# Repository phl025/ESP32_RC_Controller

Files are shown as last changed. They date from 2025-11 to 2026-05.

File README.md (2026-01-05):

# Arduino RC Controller for ESP32



## Description
This is a RC controller including engine sound player, PWM outputs for servos, ESC drivers and digital outputs.

## Details
It is based on *'Rc_Engine_Sound_ESP32'* : https://github.com/TheDIYGuy999/Rc_Engine_Sound_ESP32.

If you need to use it for trucks, cars, or other vehicles, it is easier to use the original version.

This version is modified for my boats.

## Software
Many functions are converted to 'object-oriented programming', such as :
- Receiver : RxBase, RxPpm, RxCrsf, RxSbus, RxPwm
- RX Channels : RxChannel, chTrigger
- ESC : escDriver for RZ7886 or IBT2
- ...

## Hardware
You can use the original hardware, but a modified version is available. 

Modifications : 
- Add pins for diagnostics or futures extensions.
- CH5, CH6 rename to IN1, IN2 (could be use for PWM input CH5, CH6 or 'motor encoder')
- Add input IN3, pin 39
- Add CH7, pin 15 (for steering servo in case of 3x ECS)

## PCB

See "hardware/pictures/"

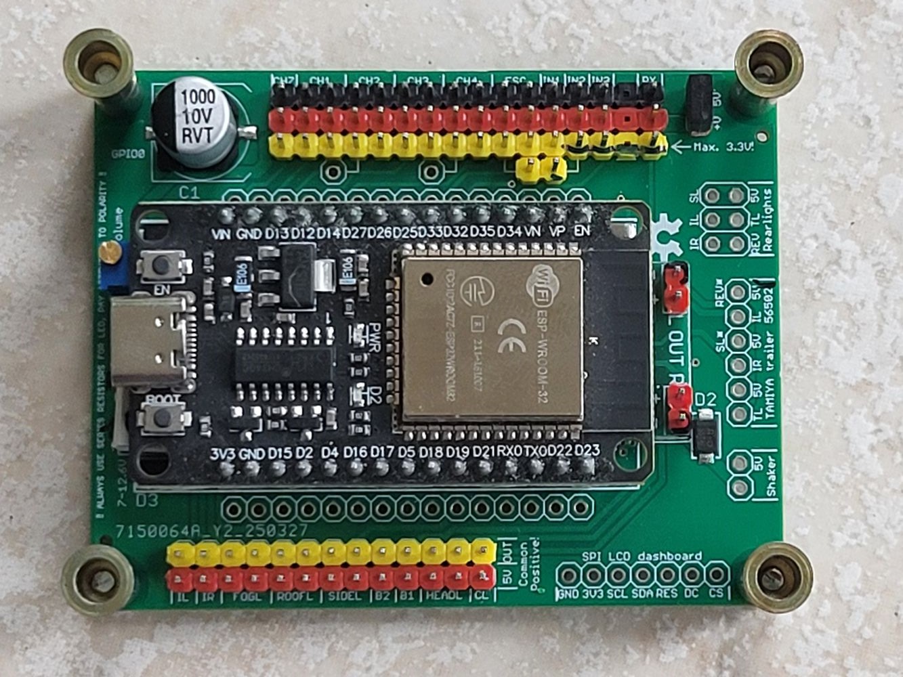
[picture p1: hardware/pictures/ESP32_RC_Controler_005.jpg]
This is a sample image.


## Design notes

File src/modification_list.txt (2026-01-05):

*
* Liste des Modifications
*

*
* Tests RX Communication modes (2025-11-09)
* 
CRSF Communication : TX16S + RP3-H (CRSF) : OK, 16ch
SBUS_Communication : TX16S + RP3-H (SBUS) : OK,
PWM_Communication  : TX16S + ER6 (PWM pins 13, 12, 14, 27, 35, 34) : OK, 4 and 6ch 
PPM_Communication  : MC2010 (Trainer output) : OK, but stability not correct (error with integrator .rxd) (2025-11-24)
--> Test https://github.com/dimag0g/PPM-reader/tree/master

*
* Models definition
*
2025-09-26 :
  - Add 0_Model.h -> Models list, call "models/model.h"
  - Add \Models and models .h
    Each 'model.h' include 
    - sound definition (idem DIYGuy999 template)
    - Remote configuration (like but does not match the DIYGuy999 template)
  Benefit : Only one file by model
  
*
* MAJ noms / convention
*
2025-09-18
  - MAJ des noms de Class, fonctions, variables.. pour coller a la convention de nomage jointe.
  - Ajout de \documents, \hardware

*
* Test PWM communication (inputs, using RTM)
*
2025-10-02
  - Ajout rxPwm.h et rxPwm.cpp
  - Test PWM_Communication (version 4 canaux)

*
* Test SBUS / CRSF
*
2025-09-26
  - Test CRSF après mise a jour de TX16S, ER6, RP3-H en version 3.6.0 -> OK sur les 16 canaux

2025-09-10 
  - Ajout, test 'rxSbus'
    -> 16 canaux OK
    -> failSafe par timeout 100ms OK
  - rxBase
    - processFailSafe() : Ajout MAJ channel[].rxd

2025-09-08
  - Premiers test, résultat moyen
  -> 16 canaux OK
  -> pas de détection failSafe, pb de temps ~200us pour 100Hz / 10000us (????)

*
* Corrections diverses pour CRSF jusqu'à 16 chanaux (15 et 16 NOK)
*
2025-09-07
  - Modifs diveres, erreurs avec 'nb_channels' et 'nb_channels + 1'
  - Limitations de nb_channels fonction de RX_CHANNELS et MAX_CHANNELS

*
* Ajout de RxChannel
*
2025-08-28 :
  - Ajout de RxChannel (objet)
  - RxChannel[] est intégré dans rxBase, 
  - raw_channel[], rx_channel[], rxd_channel[] : sont supprimés
  - Tests semblent OK 

*
* Test module sonore :
*
2025-08-13 :
  - Idle engine 	: OK,
	- Rev Engine 	: OK,
  - Horn (sound1) : OK (08-2x)
  - Winch (sound2) : OK (08-2x)

*
* Test ESC
*
2025-04-23 : 
- ESC1 a ESC3 OK, avec allocation dynamique
- CRSFForArduino, testé : OK, A revoir pour faire un objet

2025-04-22 : 
- ESC1 et ESC2 OK, avec allocation statique "escDriver esc_1(1, MCPWM_UNIT_1, ..);"
  -> Les variables de la classe doivent être déclarées dans escDriver.h 
     (Ne fonctionne pas dans .cpp, erreur d'allocation mémoire)

2025-04-19 :
- Test ESC_1 : OK
  Ajout gestion des rampes, idem variateur AVR-
- Test ESC_2 : 
	--> NOK, reboot CPU  

2025-04-15 :
- Test rxCrsf avec TX16S + ER6 : OK
  Les canaux 1 a 9 sont mis a jour

2025-04-14 :
- Test rxPpm avec MC2020 : OK (pour controle)

*
* Tests modules externes
*
CRSFForArduino : 
- Semble pas stable, saut de valeurs alors que c'est OK avec "AlfredoCRSF".
- Retiré du projet (2025-05-14)

*
* EOF
*

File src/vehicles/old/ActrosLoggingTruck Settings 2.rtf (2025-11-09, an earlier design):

/* ******* RECOMMENDED Audacity Settings: 22'050 Hz, 8 bit PCM **********

// Sound files converted with: https://bitluni.net/wp-content/uploads/2018/01/Audio2Header.html
// converter code by bitluni (send him a high five, if you like the code)

Recommended parts & settings for TAMIYA King Hauler:

ESC: HOBBYWING QUICRUN WP Crawler Brushed with the following settings:
1: 3
2: 1
3: 3
4: 3
5: 4
6: 2
7: 9
8: 1
9: 8 (change it, important)
10: 4
11: 4
12: 5
13: 4
14: 1 (be careful here!!)
15: 1 (change it, important)

Motor: 540 size, 35 turns, stock pinion

// ********************************************************************************************************************* */
// Choose the board version
//#define PROTOTYPE_36 // 36 or 30 pin board (do not uncomment it or it will cause boot issues!)

// ---------------------------------------------------------------------------------------------------------------------
// Choose the receiver communication mode (never uncomment more than one! If all commented out = classic PWM RC signal communication)--
// SBUS communication --------
#define SBUS_COMMUNICATION // control signals are coming in via the SBUS interface (comment it out for classic RC signals)

boolean sbusInverted = true; // false = wired to NPN transistor signal inverter or uninverted SBUS signal (for example from "Micro RC" receiver)

// Serial communication --------
//#define SERIAL_COMMUNICATION // control signals are coming in via the serial interface (comment it out for classic RC signals)
// Only for my "Micro RC" receiver! See: https://github.com/TheDIYGuy999/Micro_RC_Receiver

// PPM communication --------
//#define PPM_COMMUNICATION // control signals are coming in via the PPM interface (comment it out for classic RC signals)
#define NUM_OF_CHL 8 // The number of channels inside our PPM signal (usually max. 8)

#define NUM_OF_AVG 1 // Number of averaging passes (usually one, more will be slow)

// Sound files (22'050 Hz, 8 bit PCM recommended) -----------------------------------------------------------------------
// Choose the start sound (uncomment the one you want) --------
volatile int startVolumePercentage = 130; // Adjust the start volume (usually = 100%)
//#include "sounds/UnionPacific2002Start.h" // Union Pacific 2002 SD70M Locomotive Start
//#include "sounds/ScaniaV8Start.h" // Scania V8 Start
//#include "sounds/ScaniaR500V8Start.h" // Scania R500 V8 Start
//#include "sounds/ScaniaV8StartNew.h" // Scania V8 Start
#include "sounds/UralV8Start.h" // Ural 4320 V8 Start (use it for Diesel trucks, if no other is available) use it for King Hauler

//#include "sounds/HgP408Start.h" // HG P408 Humvee Diesel (only for small speakers)
//#include "sounds/DefenderV8Start.h" // Land Rover Defender V8 Start
//#include "sounds/JaguarXjsHeStart.h" // Jaguar XJS HE Starts
//#include "sounds/KenworthW900Start.h" // Kenworth W900 Truck Start
//#include "sounds/MackStart.h" // Mack Truck Start
//#include "sounds/DetroitDieselStart.h" // Detroit Diesel generic Truck Start
//#include "sounds/InternationalDT-466Start.h" // International DT-466 Start
//#include "sounds/Cat3406BStart.h" // Caterpillar 3406B start
//#include "sounds/ActrosV8Start.h" // MB Actros V8 Truck Start
//#include "sounds/VWBeetleStart.h" // VW Beetle or Bug
//#include "sounds/HarleyDavidsonFXSBStart.h" // Harley Davidson FXSB start
//#include "sounds/v8soundteststart.h" // Wombii's Scania V8 Fire Truck start
//#include "sounds/JeepGrandCherokeeTrackhawkStart.h" // Jeep Grand Cherokee Trackhawk start
//#include "sounds/carCranking.h" // Generic car cranking

// Choose the motor idle sound (uncomment the one you want) --------
volatile int idleVolumePercentage = 50; // Adjust the idle volume (usually = 100%, more also working, depending on sound, 50 - 60% if additional diesel knock sound is used)
volatile int engineIdleVolumePercentage = 100; // the engine volume will be throttle dependent (usually = 40%, never more than 100%!)
//#include "sounds/20Hz.h" // 20Hz test tone
//#include "sounds/100Hz.h" // 100Hz test tone
//#include "sounds/1000Hz.h" // 1000Hz test tone
//#include "sounds/UnionPacific2002Idle.h" // Union Pacific 2002 SD70M Locomotive with 16 cylinder Diesel (set volume to 60%)
//#include "sounds/ScaniaV8Idle.h" // Scania V8 (bad quality)
//#include "sounds/ScaniaR500V8Idle.h" // Scania R500 V8
//#include "sounds/ScaniaV8IdleNew.h" // Scania V8 (Volume 100%, 35%, Turbo 70%, 10%, Wastegate 50%, 1%, CEP 100, TSM 2)
//#include "sounds/ScaniaV8IdleNewWarm.h" // Scania V8 (Volume 55%, 40%, Turbo 70%, 10%, Wastegate 200%, 1%, CEP 100, TSM 3, Knock volume 600, 10%, interval 1, 150) the best one!
//#include "sounds/ScaniaR620V8Idle2.h" // Scania R620 V8 (a bit thin, add about 80% turbo volume)
//#include "sounds/ScaniaR620Uphill.h" // Scania R620 V8 going uphill, typical knock - knock under load
//#include "sounds/ScaniaR620Uphill2.h" // Scania R620 V8 going uphill, typical knock - knock under load (this one is better, Volume 180%, 20%, Turbo 60%, 10%, Wastegate 50%, 1%, CEP 100, TSM 2)
//#include "sounds/SCANIAV850TonIdle.h" // 50 ton SCANIA going uphill @ very low rpm (Volume 60%, 40%, Turbo 40%, 10, Wastegate 100%, 1%, CEP 100, TSM 2, Knock volume 600, 0%, interval 4, 50)
//#include "sounds/UralV8Idle.h" // Ural 4320 V8
//#include "sounds/HumveeDieselIdle.h" // "Humvvee" (Hummer H1) V8 Diesel
//#include "sounds/HgP408Idle.h" // HG P408 Humvee Diesel (only for small speakers)
//#include "sounds/DetroitDieselIdle.h" // Detroit Diesel generic Truck (Volume 80%, 30%, Turbo 60%, 10%, Wastegate 50%, 1%, CEP 100, TSM 3)
//#include "sounds/DetroitDieselStraightPipeIdle.h" // Detroit Diesel Truck with straight pipes (use multiplier = 2, acc = 2, dec = 1)
//#include "sounds/DetroitDieselBassBoost15db.h" // Detroit Diesel Truck with straight pipes. Bass 100-200Hz + 15dB
//#include "sounds/DetroitDieselBassBoost7db.h" // Detroit Diesel Truck with straight pipes. Bass 100-200Hz + 7dB (use it for King Hauler, Volume 60%, 40%, Turbo 60%, 10, Wastegate 100%, 1%, CEP 100, TSM 3, Knock volume 400, 10%, interval 2, 50)
//#include "sounds/DetroitDieselPeterbiltCabover.h" // Detroit Diesel Peterbilt cabover truck
//#include "sounds/DetroitDieselKenworth.h" // Detroit Diesel Kenworth truck (use Ural V8 Start & 100% turbo)
//#include "sounds/DetroitDieselJohnDeereTractor.h" // Detroit Diesel John Deere tractor
//#include "sounds/InternationalDT-466Idle.h" // International DT-466 idle (Volume 100%, 35%, Turbo 60%, 10%, Wastegate 30%, 1%, CEP 100, TSM 3)
//#include "sounds/Cat3406BIdle.h" // Caterpillar 3406B idle (Volume 100%, 35%, Turbo 70%, 10%, Wastegate 30%, 1%, CEP 100, TSM 3)
//#include "sounds/M35Idle.h" // AM General M35 Truck
//#include "sounds/M35BassBoost7db.h" // AM General M35 Truck Bass 100-200Hz + 7dB (Volume 100%, 35%, Turbo 100%, 30%)
//#include "sounds/UnimogU1000TurboFullLoad.h" // Unimog U1000 Turbo (Volume 100%, 35%, Turbo 50%, 10%, Wastegate 150%, 1%)
//#include "sounds/ActrosV8Idle.h" // MB Actros V8 Truck Idle (very noisy)
//#include "sounds/ActrosLoggingTruckIdling.h" // Actros logging truck (Volume 80%, 40%, Turbo 60%, 10, Wastegate 100%, 1%, CEP 100, TSM 2, Knock volume 200, 10%, interval 4, 50)
#include "sounds/ActrosLoggingTruckIdling2.h" // Actros logging truck (Volume 50%, 100%, Turbo 10%, 10, Wastegate 100%, 1%, CEP 100, TSM 3, Knock volume 500, 10%, interval 2, 50, ActrosLoggingTruckDieselKnock3.h)

//#include "sounds/KenworthW900Idle.h" // Kenworth W900 Truck Idle (Volume 80%, 30%, Turbo 60%, 10%, Wastegate 50%, 1%, CEP 100, TSM 2)
//#include "sounds/MackIdle.h" // Mack Truck Idle (very thin)
//#include "sounds/Tatra813Idle.h" // Tatra 813 8x8 air cooled V12 Diesel (Volume 80%, 50%, Turbo 0%, 0, Fan 250, 0, 250, No Wastegate, CEP 100, TSM 2, Knock volume 500, 0%, interval 2, 50)
//#include "sounds/DefenderV8Idle.h" // Land Rover Defender V8 (Volume 100%, 40%, Turbo 0%, 0, Fan 0, 0, 250, No Wastegate, CEP 100, TSM 2, Knock volume 500, 0%, interval 2, 50, automatic = true)
//#include "sounds/Mustang68Idle.h" // Ford Mustang 1968
//#include "sounds/DodgeChallenger70Idle.h" // 1970 Dodge Challenger
//#include "sounds/MgBGtV8Idle.h" // MG B GT V8
//#include "sounds/LaFerrariIdle.h" // Ferrari "LaFerrari"
//#include "sounds/chevyNovaV8Idle.h" // Chevy Nova Coupe 1975
//#include "sounds/V8TrophyTruckIdle.h" // V8 Trophy Truck
//#include "sounds/JaguarXjsHeIdle.h" // Jaguar XJS HE (bad quality)
//#include "sounds/VWBeetleIdle.h" // VW Beetle or Bug
//#include "sounds/HarleyDavidsonFXSBIdle.h" // Harley Davidson FXSB (Volume 60%, 40%, Turbo 0%, 10, no Wastegate 100%, CEP 300, TSM 4, Knock volume 300, 10%, interval 2, 50)
//#include "sounds/v8soundtestidle.h" // Wombii's Scania V8 Fire Truck (Volume 90%, 50%, Turbo 20%, 10, Wastegate 90%, 1%, CEP 100, TSM 3, Knock volume 350, 15%, interval 4, 10, ScaniaDieselKnock.h)
//#include "sounds/JeepGrandCherokeeTrackhawkIdle.h" // Jeep Grand Cherokee Trackhawk idle (speaker with good bass required)
//#include "sounds/DAFXFIdle.h" // DAF XF truck

// Choose the motor revving sound (uncomment the one you want) --------
//#define REV_SOUND // uncomment this, if you want to use the separate, optional rev sound
volatile int revVolumePercentage = 150; // Adjust the idle volume (usually = 100%, more also working, depending on sound)
volatile int engineRevVolumePercentage = 30; // the engine volume will be throttle dependent (usually = 40%, never more than 100%!)
const uint8_t revSwitchPoint = 250; // The rev sound is played instead of the idle sound above this point
#ifdef REV_SOUND

//#include "sounds/ScaniaV8Rev.h" // Scania V8
#include "sounds/ScaniaV8Rev2.h" // Scania V8

#endif

// Choose the Diesel (or whatever) ignition "knock" sound (played in the fixed sampling rate interrupt, uncomment the one you want,
// play around here, the results are amazing, if you hit the right combination with the idle sound!) --------
volatile int dieselKnockVolumePercentage = 500; // Adjust the Diesel knock volume (usually = 200 - 600%)
volatile int dieselKnockIdleVolumePercentage = 10; // Diesel knock volume while idling (usually = 20%)
volatile int dieselKnockInterval = 2; // Idle sample length divided by this number (1 - 20, depending on sound files)
volatile int dieselKnockStartPoint = 10; // Volume will raise above this point ( usually 0, for "open pipe" exhaust about 250)
//#define ADAPTIVE_KNOCK_VOLUME // Experimental setting: only the first knock per engine cycle will be full volume!
volatile int dieselKnockAdaptiveVolumePercentage = 50; // Adjust the Diesel knock volume for the non-first knocks per engine cycle (usually = 50%)
//#include "sounds/DieselKnockDummy.h" // If you don't want Diesel knock sound
//#include "sounds/ScaniaR620UphillKnock.h" // Scania R620 V8 (use it for King Hauler)
//#include "sounds/LanzBulldogDieselKnock.h" // Lanz Bulldog tractor (Interval = 2)
//#include "sounds/ScaniaDieselKnock.h" // Strong Scania V8 diesel knock while highway race against Volvo truck (500%, 10%, Interval = 2 possible, for slow running V8 engines)
//#include "sounds/ScaniaDieselKnock2.h" // Strong, short Scania V8 diesel knock while highway race against Volvo truck (Interval = 4 possible, for faster running engines)
//#include "sounds/ScaniaR730V8DieselKnockShort.h" // Hard knock (400%, 0%, Interval = up to 8 possible, for small engines)
//#include "sounds/ScaniaR730V8DieselKnockSlow.h" // Soft knock (500%, 10%, Interval = up to 4 possible, for meduim engines and Scania open pipe (interval = 1))
//#include "sounds/SCANIAV850TonKnock.h" // 50 ton SCANIA knock
//#include "sounds/ActrosLoggingTruckDieselKnock.h" // Actros logging truck
//#include "sounds/ActrosLoggingTruckDieselKnock2.h" // Actros logging truck
#include "sounds/ActrosLoggingTruckDieselKnock3.h" // Actros logging truck (same as idle, for testing)

//#include "sounds/Tatra813Knock.h" // Tatra 813 8x8 air cooled V12 Diesel
//#include "sounds/Tatra813Roar.h" // Tatra 813 8x8 air cooled V12 Diesel (use this for 813)
//#include "sounds/Tatra813RoarShort.h" // Tatra 813 8x8 air cooled V12 Diesel
//#include "sounds/HarleyDavidsonFXSBKnock.h" // Harley Davidson FXSB knock
//#include "sounds/DefenderV8Knock.h" // Land Rover Defender V8 knock (experimental, don't use it)
//#include "sounds/DefenderV8Knock2.h" // Land Rover Defender V8 knock (experimental, don't use it)
//#include "sounds/DefenderV8Knock3.h" // Land Rover Defender V8 knock (experimental, don't use it)
//#include "sounds/DefenderV8Knock4.h" // Land Rover Defender V8 knock (experimental, don't use it)
//#include "sounds/V8TrophyTruckKnock.h" // V8 Trophy Truck
//#include "sounds/chevyNovaV8Knock.h" // Chevy Nova Coupe 1975
//#include "sounds/JeepGrandCherokeeTrackhawkKnock.h" // Jeep Grand Cherokee Trackhawk knock
//#include "sounds/TrackhawkKnock.h" // Jeep Grand Cherokee Trackhawk knock, the more aggressive one!
//#include "sounds/DAFXFKnock.h" // DAF XF truck

// Adjust the additional turbo sound (set "turboVolumePercentage" to "0", if you don't want it) --------
volatile int turboVolumePercentage = 10; // Adjust the turbo volume (usually = 70%)
volatile int turboIdleVolumePercentage = 10; // the turbo volume will be engine rpm dependent (usually = 10%)
#include "sounds/TurboWhistle.h" // Turbo sound, playing in parallel with engine sound!

// Adjust the additional supercharger sound (set "chargerVolumePercentage" to "0", if you don't want it) --------
volatile int chargerVolumePercentage = 0; // Adjust the supercharger volume (usually = 70%)
volatile int chargerIdleVolumePercentage = 10; // the supercharger volume will be engine rpm dependent (usually = 10%)
volatile int chargerStartPoint = 10; // Volume will raise above this point ( usually 10)
#include "sounds/supercharger.h" // supercharger sound, playing in parallel with engine sound!

// Adjust the additional turbo wastegate / blowoff valve sound (set "wastegateVolumePercentage" to "0", if you don't want it)--------
volatile int wastegateVolumePercentage = 100; // Adjust the wastegate volume (usually = 70%, up to 250%)
volatile int wastegateIdleVolumePercentage = 1; // Wastegate sound is played, after rapid throttle drop with engaged clutch
//#include "sounds/WastegateDummy.h"
//#include "sounds/UnimogU1000TurboWastegate.h"
#include "sounds/ScaniaR730V8TurboWastegate.h"

// Adjust the additional cooling fan sound (set "fanVolumePercentage" to "0", if you don't want it) --------
volatile int fanVolumePercentage = 0; // Adjust the fan volume (250% for Tatra 813, else 0%)
volatile int fanIdleVolumePercentage = 0; // the fan volume will be engine rpm dependent (usually = 10%)
volatile int fanStartPoint = 250; // Volume will raise above this point (250 for Tatra 813)
//#include "sounds/Tatra813Fan.h" // Tatra 813 8x8 V12 Diesel Cooling Fan
#include "sounds/Tatra813FanNew.h" // Tatra 813 8x8 V12 Diesel Cooling Fan (use this)

//#include "sounds/Tatra813FanNewSlow.h" // Tatra 813 8x8 V12 Diesel Cooling Fan

// Choose the horn sound (uncomment the one you want) --------
volatile int hornVolumePercentage = 100; // Adjust the horn volume (usually = 100%)
//#include "sounds/TrainHorn.h" // American train horn
//#include "sounds/HornblastersOUTLAWTrainHornLong.h" // Hornblasters outlaw train horn long
//#include "sounds/HornblastersOUTLAWTrainHornShort.h" // Hornblasters outlaw train horn short
#include "sounds/ManTgeHorn.h" // MAN TGE truck horn (King Hauler)

//#include "sounds/westinghouseHorn.h" // American truck horn (the best)
//#include "sounds/FireTruckAirHorn.h" // US fire truck air horn
//#include "sounds/CarHorn.h" // A boring car horn
//#include "sounds/TruckHorn.h" // A generic truck horn
//#include "sounds/PeterbiltHorn.h" // A Peterbilt truck horn
//#include "sounds/2ToneTruckHorn.h" // A 2 tone truck horn

// Choose the siren / additional horn sound (uncomment the one you want) --------
volatile int sirenVolumePercentage = 100; // Adjust the siren volume (usually = 100%)
#include "sounds/sirenDummy.h" // If you don't want siren sound

//#include "sounds/UsPoliceSiren.h" // US Police siren
//#include "sounds/FireTruckAirSiren.h" // US fire truck air siren (King Hauler)
//#include "sounds/FeuerwehrMartinshorn.h" // European Feuerwehr Martinshorn
//#include "sounds/IrishFireEngineHorn.h" // Irish fire truck horn
//#include "sounds/siren01norskere22.h" // Norwegian siren
//#include "sounds/PostAutoHorn.h" // The typical Swiss post bus horn

// Choose the air brake release sound (uncomment the one you want) --------
volatile int brakeVolumePercentage = 150; // Adjust the brake volume (usually = 200%)
//#include "sounds/AirBrakeDummy.h" // If you don't want air brake sound
//#include "sounds/TruckAirBrakes.h" // Short truck air brake sound
//#include "sounds/TruckAirBrakesLong.h" // Long truck air brake sound
#include "sounds/TruckAirBrakes2.h" // Another truck air brake sound

//#include "sounds/AirBrakeSqueak.h" // Squeaky air brake sound

// Choose the parking brake engaging sound (uncomment the one you want) --------
volatile int parkingBrakeVolumePercentage = 150; // Adjust the brake volume (usually = 200%)
//#include "sounds/ParkingBrakeDummy.h" // If you don't want parking brake sound
#include "sounds/ParkingBrake.h" // Parking brake sound

// Choose the gear shifting sound (uncomment the one you want) --------
volatile int shiftingVolumePercentage = 200; // Adjust the shifting volume (usually = 200%)
//#include "sounds/AirShiftingDummy.h" // If you don't want pneumatic shifting sound
//#include "sounds/AirShifting.h" // Pneumatic shifting sound
#include "sounds/ClunkingGearShifting.h" // Manual clunking shifting sound

// Choose the additional "sound1" (uncomment the one you want) --------
volatile int sound1VolumePercentage = 100; // Adjust the sound1 volume (usually = 100%)
//#include "sounds/EMDLocomotiveBell.h" // American EMD locomotive bell
//#include "sounds/007JamesBond.h" // James Bond melody
//#include "sounds/M2Fire.h" // M2 salve
//#include "sounds/GlenCanyon.h" // Glen Canyon country song for truckers ;-)
#include "sounds/door.h" // opening and closing the door

// Choose the reversing beep sound --------
volatile int reversingVolumePercentage = 70; // Adjust the reversing sound volume (usually = 70%)
#include "sounds/TruckReversingBeep.h" // 1000Hz peep sound

// Choose the indicator / turn signal options --------
const boolean indicators = true; // "true", if you want to trigger indicator lights (turn signals)
volatile int indicatorVolumePercentage = 100; // Adjust the indicator sound volume (usually = 100%)
const uint16_t indicatorOn = 300; // The indicator will be switched on above +/- this value, if wheels are turned
const boolean INDICATOR_DIR = true; // adjust indicator direction with true or false
#include "sounds/Indicator.h" // "Tick-Tack" sound

// Choose the blue light options -----------------------------------------------------------------------------------------
const boolean doubleFlashBlueLight = true; // double flash blue lights if "true", "rotating" beacons if "false"

// PWM input signal range calibration ------------------------------------------------------------------------------------
const uint16_t pulseNeutral = 30; // pulseZero +/- this value (30) is the neutral range
const uint16_t pulseSpan = 490; // pulseZero +/- this value (max. 500 or less depending on remote signal range)
const boolean THROTTLE_DIR = false; // adjust throttle direction with true or false

// PWM ESC output signal range calibration (connect crawler type ESC to pin 33)-------------------------------------------
const int16_t escPulseSpan = 1000; // pulseZero +/- this value (> 500 = limited top speed, about 1000 for King Hauler)
const uint8_t escRampTimeFirstGear = 20; // determines, how fast the acceleration and deceleration happens (about 15 - 25, 20 for King Hauler)
const uint8_t escRampTimeSecondGear = 50; // 50 for King Hauler (this value is always in use for automatic transmission, about 80)
const uint8_t escRampTimeThirdGear = 75; // 75 for King Hauler
const uint8_t escBrakeSteps = 30; // determines, how fast the ESC is able to brake down (20 - 30, 30 for King Hauler)
const uint8_t escAccelerationSteps = 3; // determines, how fast the ESC is able to accelerate (2 - 3, 3 for King Hauler)

// Horn trigger signal type (true / false)-------------------------------------------------------------------------------
const boolean pwmSoundTrigger = true; // horn triggered by RC PWM signal instead of constant high level signal, if "true"
// Do NOT enable this boolean, if no PWM signal is connected or you will experience huge engine RPM resopnse delays

// Gearbox parameters (select number of automatic gears in curves.h)-----------------------------------------------------
const boolean automatic = false; // false = linear rpm curve, true = automatic transmission with torque converter is simulated (use it, if you don't have a real shifting transmission)
const boolean doubleClutch = false; // do not activate it at the same time as automatic!
const boolean shiftingAutoThrottle = true; // For Tamiya 3 speed tansmission, throttle is altered for synchronizing, if "true"

// Clutch parameters ---------------------------------------------------------------------------------------------------
uint16_t clutchEngagingPoint = 100; // CEP. The "clutch" is engaging above this point = engine rpm sound in synch with ESC power

// Shaker parameters (simulating engine vibrations) ---------------------------------------------------------------------
const uint8_t shakerStart = 100; // Shaker power while engine start (max. 255, about 100)
const uint8_t shakerIdle = 49; // Shaker power while idling (max. 255, about 49)
const uint8_t shakerFullThrottle = 40; // Shaker power while full throttle (max. 255, about 40)
const uint8_t shakerStop = 60; // Shaker power while engine stop (max. 255, about 60)

// Engine parameters ----------------------------------------------------------------------------------------------------
//Activate for "engine on off" functionality in combination with "Micro RC" Receiver from TheDIYGuy999. No Pulse Zero auto calibration in this case!!
const boolean engineManualOnOff = false;

// Engine RPM range (2 for big Diesels, 4 for fast running motors)
const uint32_t TOP_SPEED_MULTIPLIER = 3; // TSM. RPM multiplier: the bigger the number, the larger the rev range, 2 - 4 is a good place to start. ESP32 will crash, if > 5 @ 22'050Hz!

// Engine mass simulation
const int8_t acc = 2; // Acceleration step (2) 1 = slow for locomotive engine, 9 = fast for trophy truck
const int8_t dec = 1; // Deceleration step (1) 1 = slow for locomotive engine, 5 = fast for trophy truck

// Vehicle type ----------------------------------------------------------------------------------------------------
// #define CATERPILLAR_MODE // For Tanks, diggers, excavators etc. which use dual throttle input on CH2 and CH3

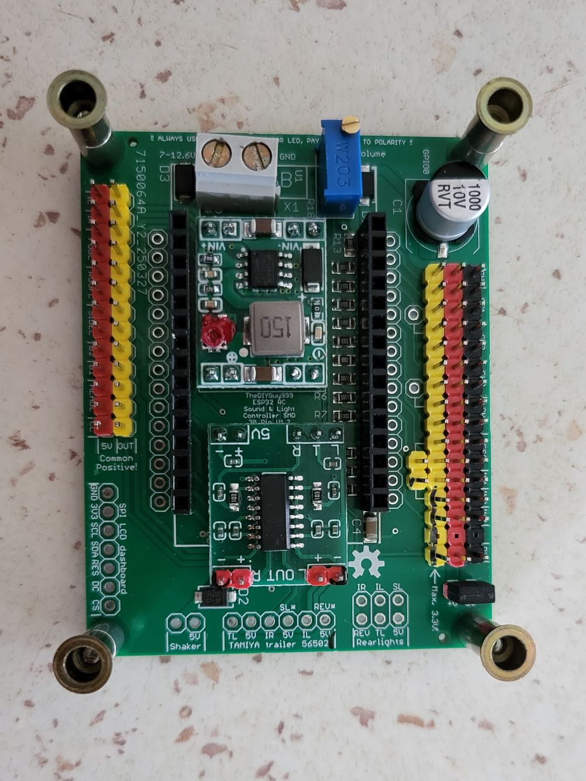
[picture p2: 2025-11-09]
hardware/pictures/ESP32_RC_Controler_001.jpg

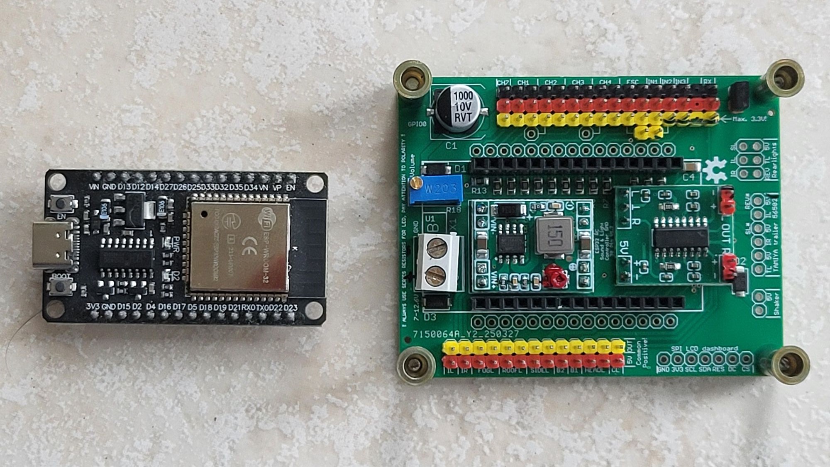
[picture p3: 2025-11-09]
hardware/pictures/ESP32_RC_Controler_007.jpg

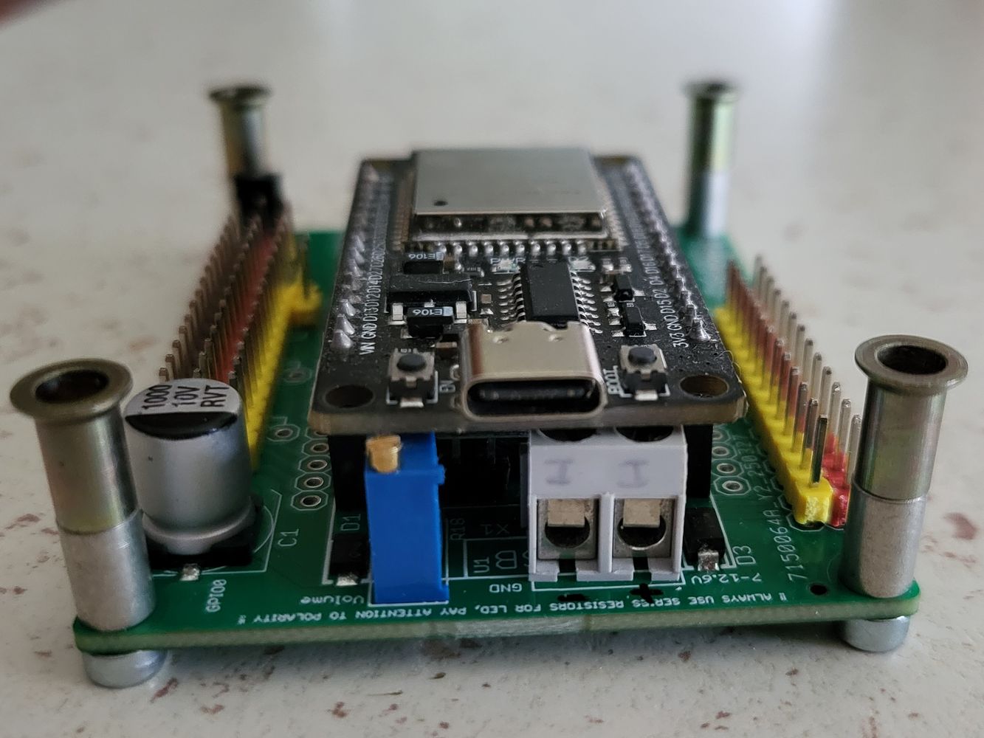
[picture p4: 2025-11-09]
hardware/pictures/ESP32_RC_Controler_003.jpg

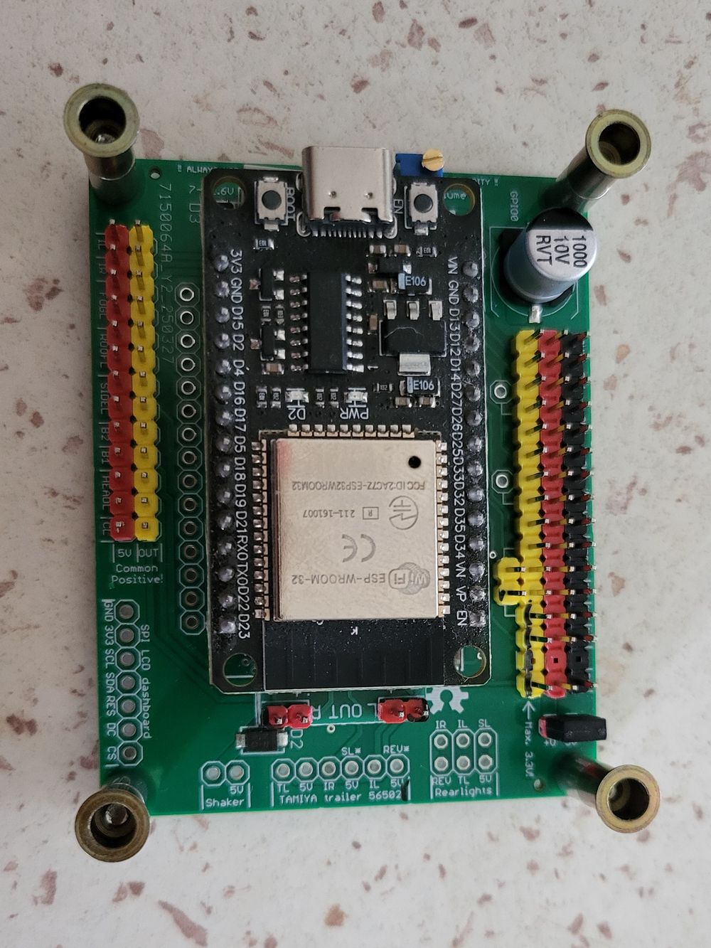
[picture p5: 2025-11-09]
hardware/pictures/ESP32_RC_Controler_002.jpg

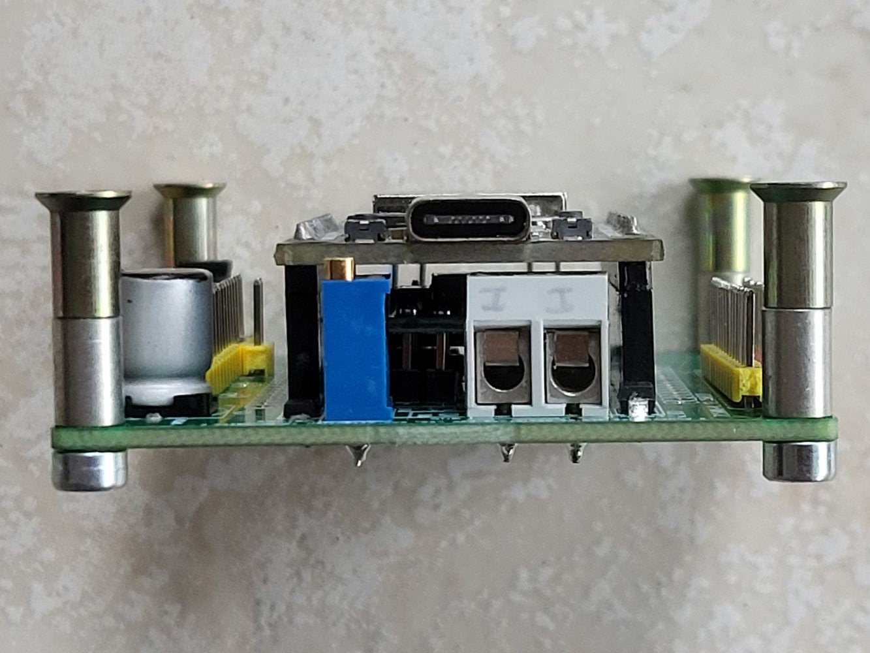
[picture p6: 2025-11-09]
hardware/pictures/ESP32_RC_Controler_008.jpg

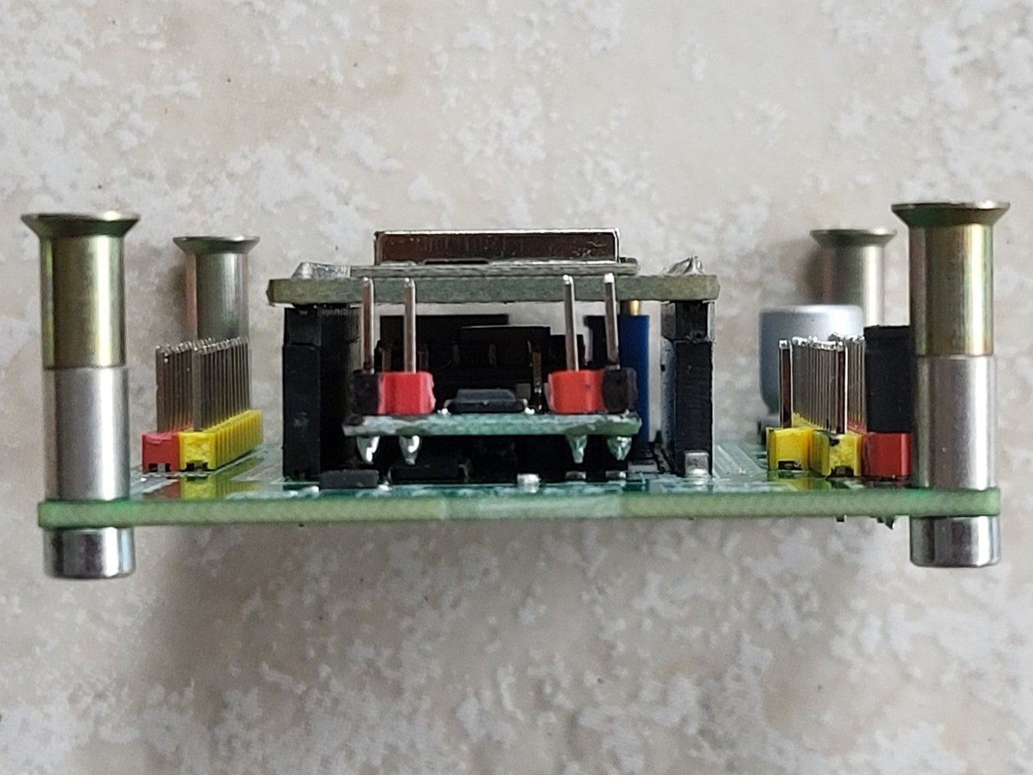
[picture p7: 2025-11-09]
hardware/pictures/ESP32_RC_Controler_009.jpg

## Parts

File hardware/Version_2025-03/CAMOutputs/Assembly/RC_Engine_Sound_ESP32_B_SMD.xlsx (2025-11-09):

Qty | Value | Device | Package | Parts | Description | MF | MPN | OC_FARNELL | OC_NEWARK | POPULARITY | PROD_ID | SPICEPREFIX
0 |  | 00_CUSTOM_PINHEAD_PINHD-1X4 | 00_CUSTOM_PINHEAD_1X04 | JP2, JP6, JP10, JP11 | PIN HEADER
0 |  | PINHD-1X2 | 1X02 | JP16, JP17, JP18, JP19, JP21, JP22, JP23, JP24, JP25, JP26, JP27, JP28, JP29, JP30, JP31 | PIN HEADER
0 |  | PINHD-1X3 | 1X03 | JP1, JP3, JP4, JP5, JP7, JP8, JP9, JP12, JP14, JP34, JPIN | PIN HEADER
0 |  | PINHD-1X6 | 1X06 | JP13 | PIN HEADER
0 |  | PINHD-1X7 | 1X07 | JP15 | PIN HEADER
0 |  | PINHD-2X3 | 2X03 | JP20 | PIN HEADER
0 |  | W237-02P | W237-132 | X1 | WAGO SREW CLAMP |  |  | unknown | unknown | 10
0 | 00_CUSTOM_PINHEAD_PINHD-1X15 | 00_CUSTOM_PINHEAD_PINHD-1X15 | 00_CUSTOM_PINHEAD_1X15 | JT1, JT2
1 | 1000uF 10V | CPOL-EUUD-10X10 | UD-10X10_NICHICON | C1 | POLARIZED CAPACITOR, European symbol |  |  |  |  | 0 |  | C
2 | 10k | R-EU_R0805 | R0805 | R11, R12 | RESISTOR, European symbol |  |  |  |  | 86 |  | R
1 | 2.2uF, 25V | C-EUC1206 | C1206 | C4 | CAPACITOR, European symbol
2 | 200R | R-EU_R0805 | R0805 | R27, R30 | RESISTOR, European symbol |  |  |  |  | 86 |  | R
1 | 20k | TRIM_EU-S64W | S64W | R18 | POTENTIOMETER |  |  |  |  | 4
11 | 330R | R-EU_R0805 | R0805 | R1, R2, R3, R4, R5, R6, R7, R8, R9, R10, R13 | RESISTOR, European symbol |  |  |  |  | 86 |  | R
1 | 47R | R-EU_R0805 | R0805 | R28 | RESISTOR, European symbol |  |  |  |  | 86 |  | R
0 | DC-DC-STEP-DOWN-MP1584 | DC-DC-STEP-DOWN-MP1584 | DC-DC-STEP-DOWN-MP1584 | U$1 | DC/DC Step-Down Regulator based on MP1584 chip
0 | ESP32DEVKITV1 | ESP32DEVKITV1 | ESP32-DEVKITV1 | U1
0 | JUMPER-PAD-3-2OF3_NC_BY_TRACE_LARGE | JUMPER-PAD-3-2OF3_NC_BY_TRACE_LARGE | PAD-JUMPER-3-2OF3_NC_BY_TRACE_YES_SILK_LARGE | JP32, JP33
0 | OSHW-LOGOM | OSHW-LOGOM | OSHW-LOGO-M | LOGO1 | Open Source Hardware Logo
0 | PAM8403_NO_SPEAKERS | PAM8403_NO_SPEAKERS | PAM8403_NO_SPEAKERS | IC4
2 | SS14F | MBRA140 | SMA-DIODE | D1, D2 | 40V, 1A Schottky rectifier |  |  |  |  |  | DIO-08053
1 | SS34 | MBRA140 | SMA-DIODE | D3 | 40V, 1A Schottky rectifier |  |  |  |  |  | DIO-08053
2 | ULN2003AD | ULN2003AD | SO16 | IC2, IC3 | DRIVER ARRAY |  |  |  |  | 2

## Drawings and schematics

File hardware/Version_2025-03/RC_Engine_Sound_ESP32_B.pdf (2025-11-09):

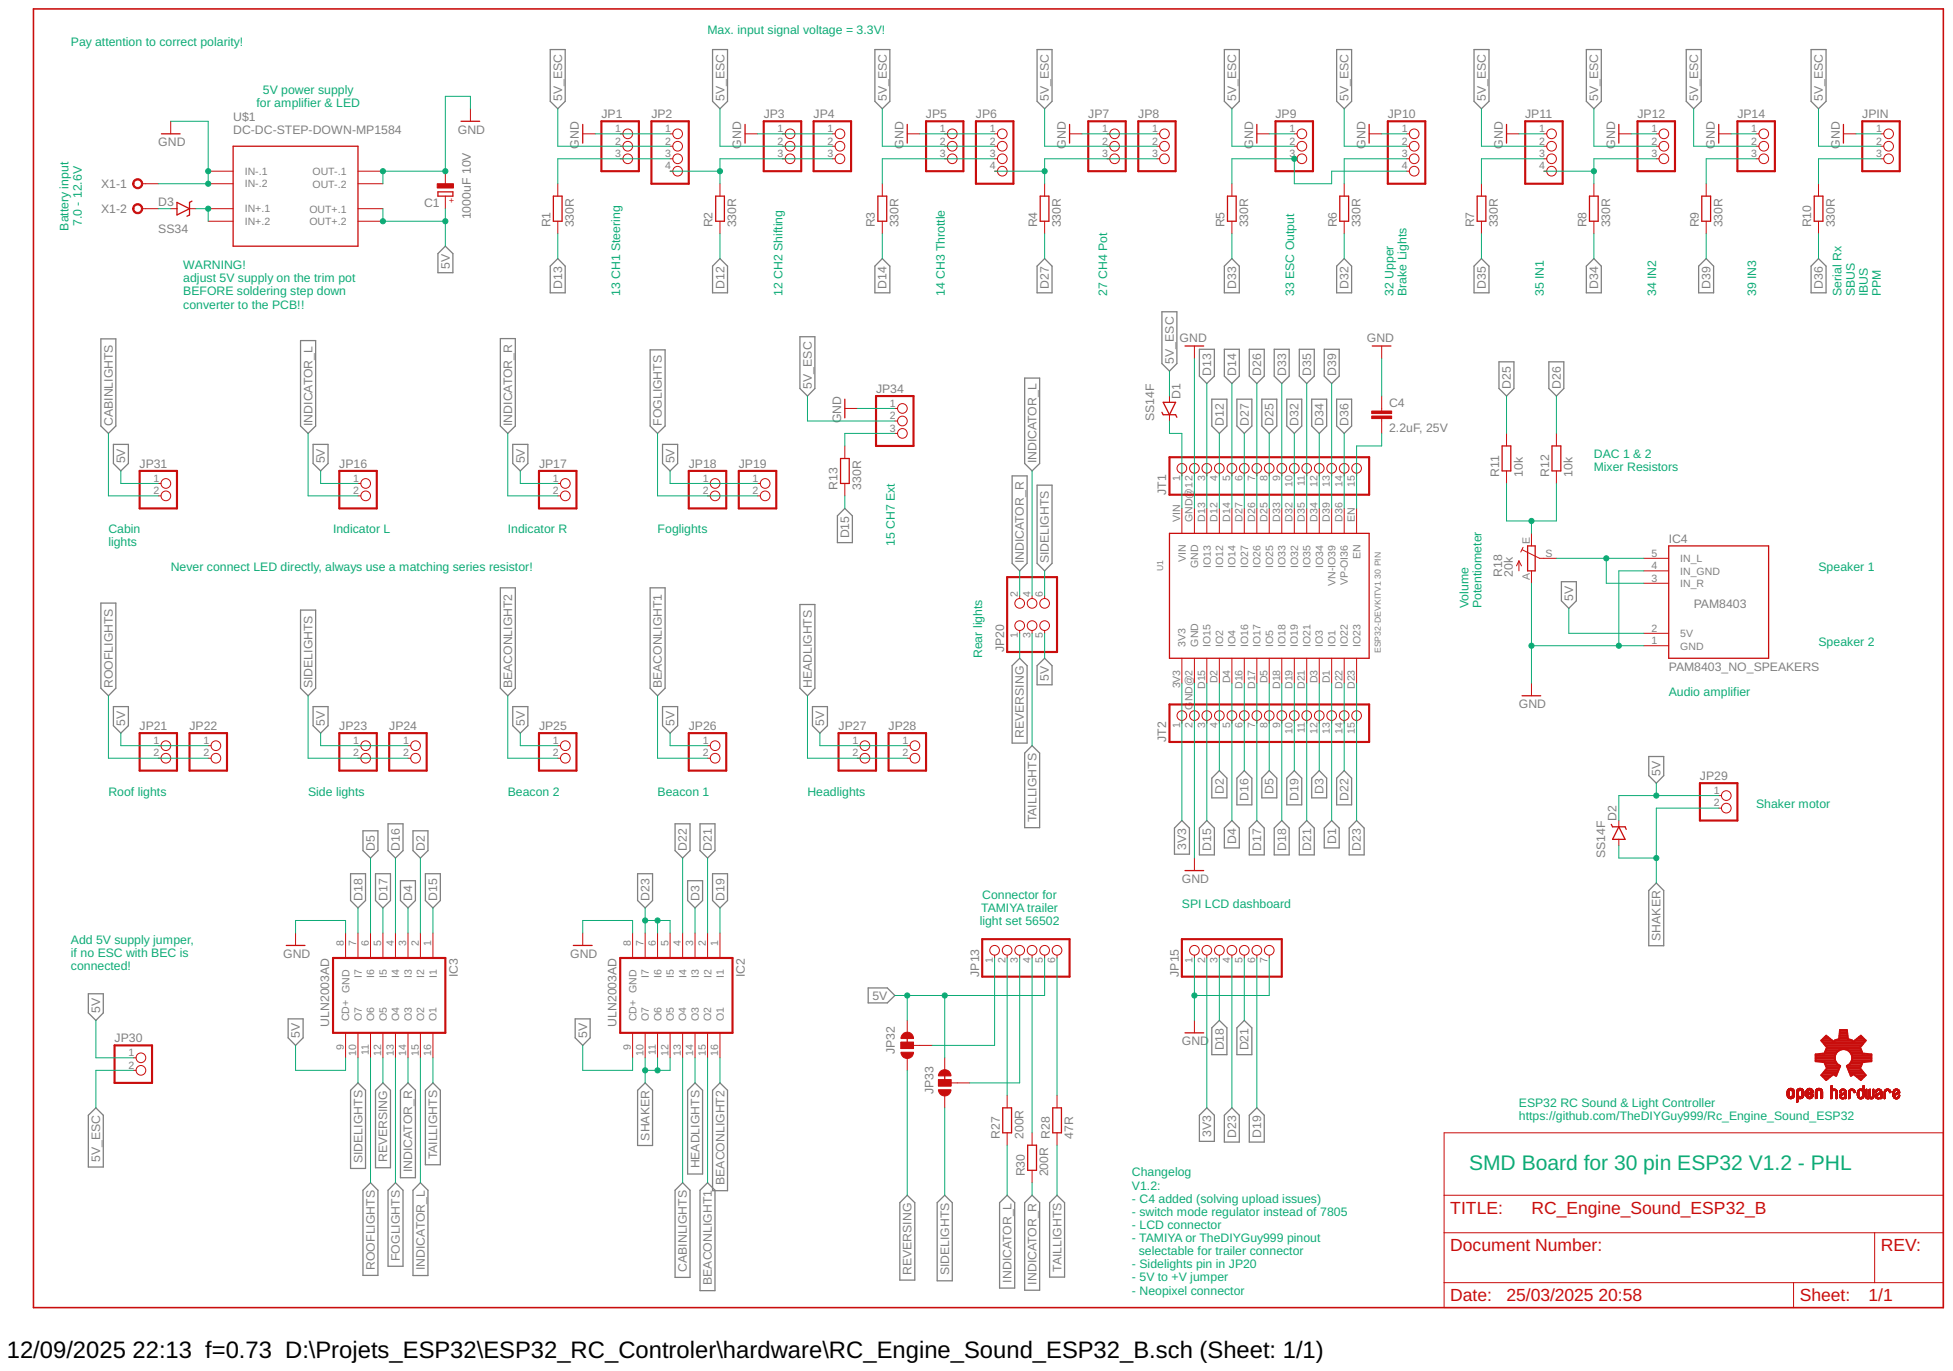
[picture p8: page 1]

DC-DC-STEP-DOWN-MP1584 GND

WARNING! adjust 5V supply on the trim pot BEFORE soldering step down

converter to the PCB!!

Never connect LED directly, always use a matching series resistor!

SPI LCD dashboard Add 5V supply jumper,

if no ESC with BEC is
connected!

ESP32 RC Sound & Light Controller https://github.com/TheDIYGuy999/Rc_Engine_Sound_ESP32

SMD Board for 30 pin ESP32 V1.2 - PHL

Changelog V1.2: - C4 added (solving upload issues)

- switch mode regulator instead of 7805
- LCD connector
- TAMIYA or TheDIYGuy999 pinout selectable for trailer connector

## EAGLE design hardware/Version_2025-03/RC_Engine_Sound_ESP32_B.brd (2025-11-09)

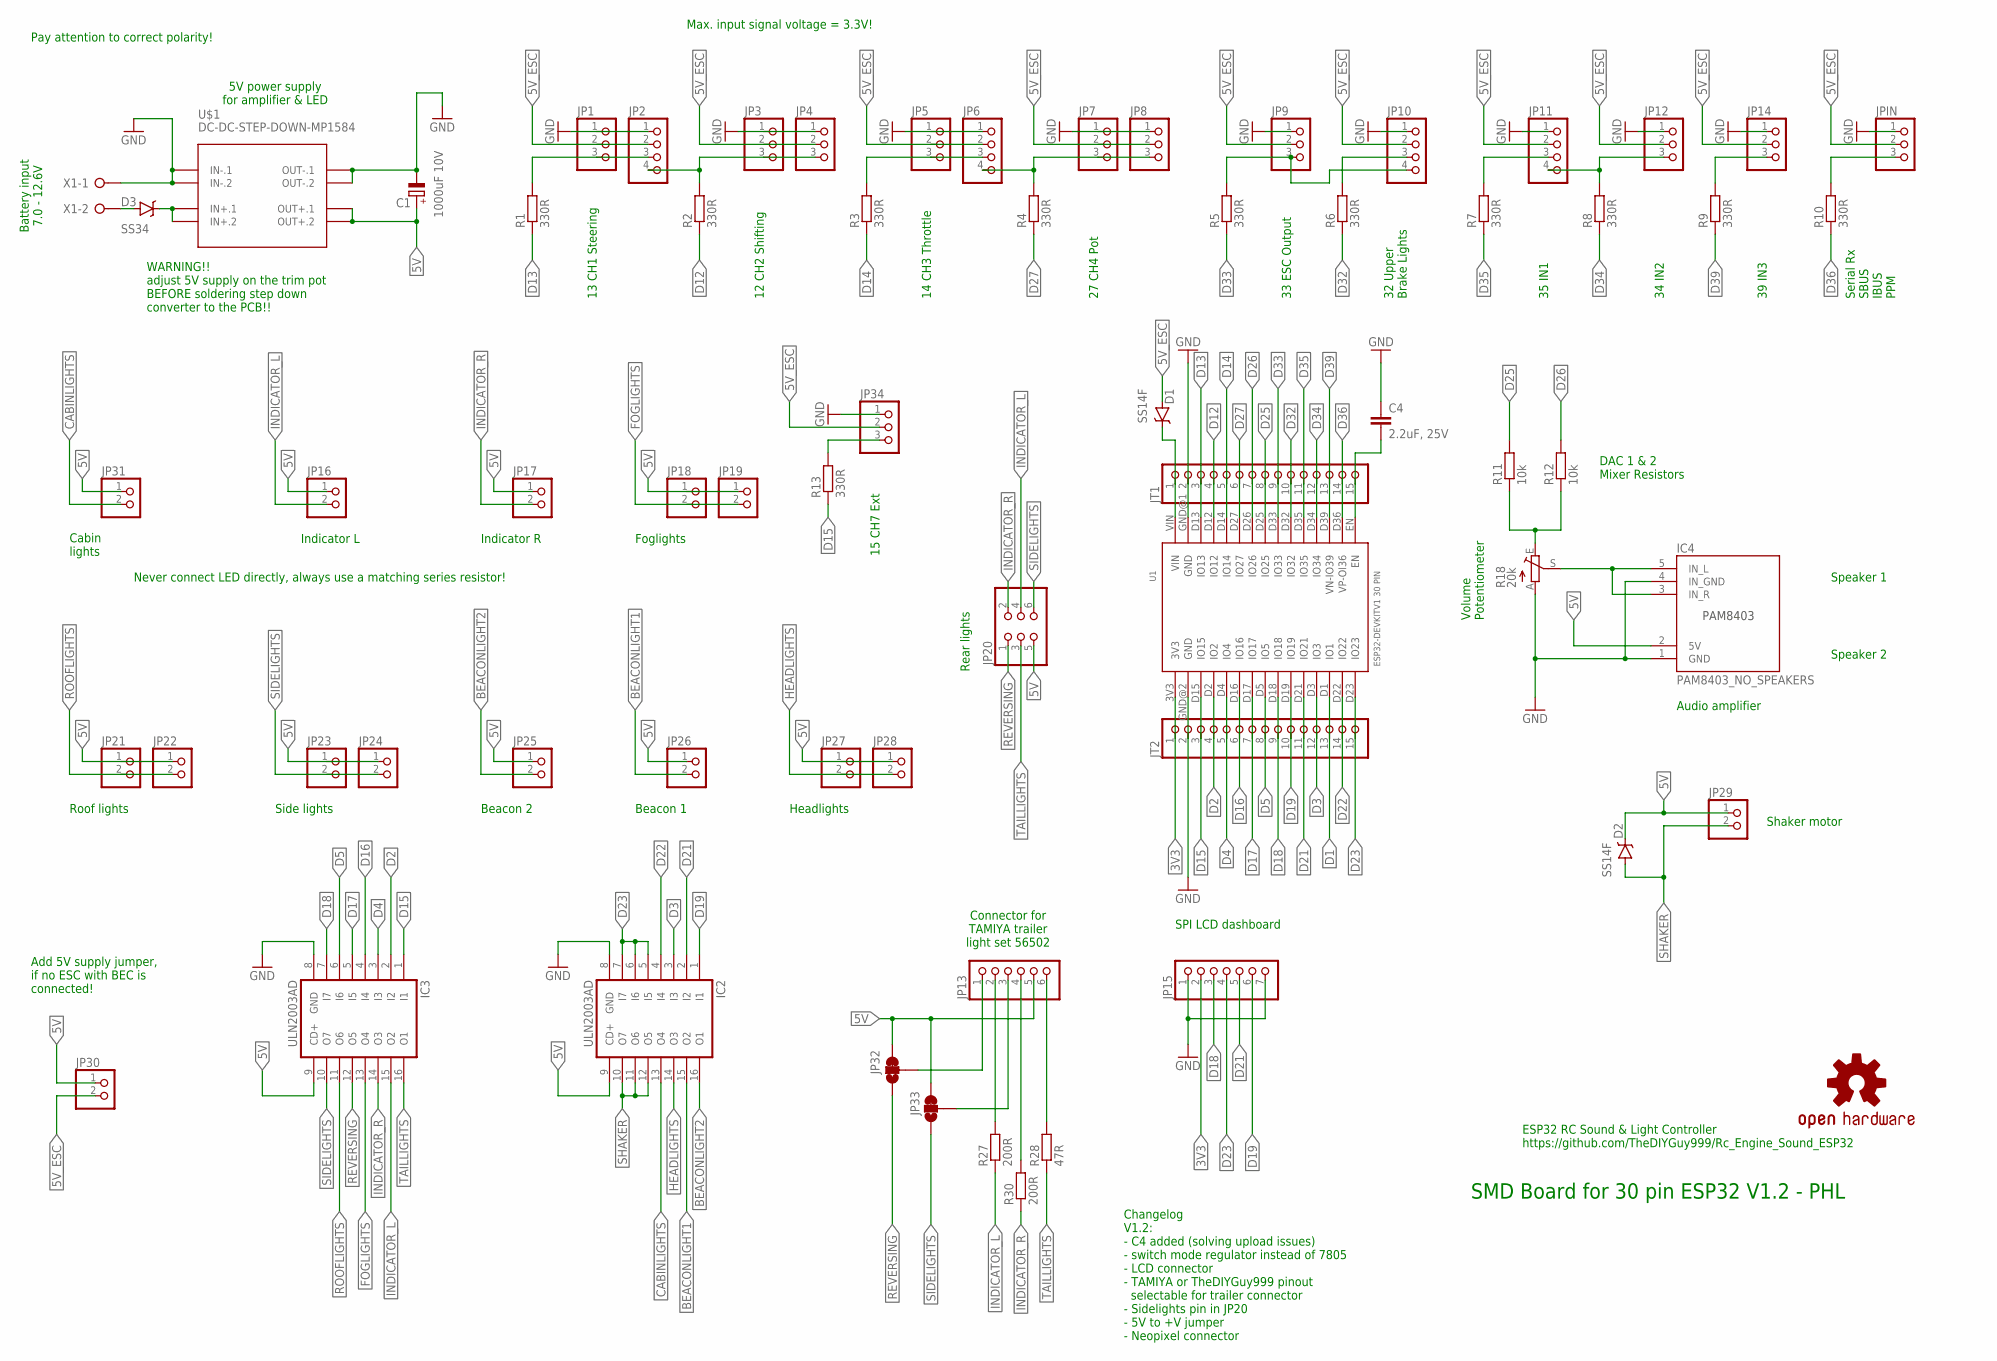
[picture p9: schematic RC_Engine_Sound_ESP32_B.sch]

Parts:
C1: 1000uF 10V; UD-10X10_NICHICON
C4: 2.2uF, 25V; C1206
D1, D2: SS14F; SMA-DIODE
D3: SS34; SMA-DIODE
IC2, IC3: ULN2003AD; SO16
IC4: PAM8403_NO_SPEAKERS
JP1, JP3, JP4, JP5, JP7, JP8, JP9, JP12, JP14, JP34: PINHD-1X3; 1X03
JP2, JP6, JP10, JP11: 00_CUSTOM_PINHEAD_PINHD-1X4; 00_CUSTOM_PINHEAD_1X04
JP13: PINHD-1X6; 1X06
JP15: PINHD-1X7; 1X07
JP16, JP17, JP18, JP19, JP21, JP22, JP23, JP24, JP25, JP26, JP27, JP28, JP29, JP30, JP31: PINHD-1X2; 1X02
JP20: PINHD-2X3; 2X03
JP32, JP33: JUMPER-PAD-3-2OF3_NC_BY_TRACE_LARGE; PAD-JUMPER-3-2OF3_NC_BY_TRACE_YES_SILK_LARGE
JPIN: PINHD-1X3; 1X03
JT1, JT2: 00_CUSTOM_PINHEAD_PINHD-1X15; 00_CUSTOM_PINHEAD_1X15
LOGO1: OSHW-LOGOM; OSHW-LOGO-M
R1, R2, R3, R4, R5, R6, R7, R8, R9, R10, R13: 330R; R0805
R11, R12: 10k; R0805
R18: 20k; S64W
R27, R30: 200R; R0805
R28: 47R; R0805
U1: ESP32DEVKITV1; ESP32-DEVKITV1
U$1: DC-DC-STEP-DOWN-MP1584
X1: W237-02P; W237-132

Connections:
3V3: JP15.2, JT2.1, U1.3V3
5V: C1.+, D2.C, IC2.9 (CD+), IC3.9 (CD+), IC4.2 (5V), JP13.5, JP16.1, JP17.1, JP18.1, JP19.1, JP20.5, JP21.1, JP22.1, JP23.1, JP24.1, JP25.1, JP26.1, JP27.1, JP28.1, JP29.1, JP30.1, JP31.1, JP32.3, JP33.3, U$1.OUT+.1, U$1.OUT+.2
5V_ESC: D1.A, JP1.2, JP2.2, JP3.2, JP4.2, JP5.2, JP6.2, JP7.2, JP8.2, JP9.2, JP10.2, JP11.2, JP12.2, JP14.2, JP30.2, JP34.2, JPIN.2
BEACONLIGHT1: IC2.15 (O2), JP26.2
BEACONLIGHT2: IC2.16 (O1), JP25.2
CABINLIGHTS: IC2.13 (O4), JP31.2
D1: JT2.13, U1.D1 (IO1)
D2: IC3.2 (I2), JT2.4, U1.D2 (IO2)
D3: IC2.3 (I3), JT2.12, U1.D3 (IO3)
D4: IC3.3 (I3), JT2.5, U1.D4 (IO4)
D5: IC3.6 (I6), JT2.8, U1.D5 (IO5)
D12: JT1.4, R2.1, U1.D12 (IO12)
D13: JT1.3, R1.1, U1.D13 (IO13)
D14: JT1.5, R3.1, U1.D14 (IO14)
D15: IC3.1 (I1), JT2.3, R13.1, U1.D15 (IO15)
D16: IC3.4 (I4), JT2.6, U1.D16 (IO16)
D17: IC3.5 (I5), JT2.7, U1.D17 (IO17)
D18: IC3.7 (I7), JP15.3, JT2.9, U1.D18 (IO18)
D19: IC2.1 (I1), JP15.6, JT2.10, U1.D19 (IO19)
D21: IC2.2 (I2), JP15.5, JT2.11, U1.D21 (IO21)
D22: IC2.4 (I4), JT2.14, U1.D22 (IO22)
D23: IC2.5 (I5), IC2.6 (I6), IC2.7 (I7), JP15.4, JT2.15, U1.D23 (IO23)
D25: JT1.8, R11.2, U1.D25 (IO25)
D26: JT1.7, R12.2, U1.D26 (IO26)
D27: JT1.6, R4.1, U1.D27 (IO27)
D32: JT1.10, R6.1, U1.D32 (IO32)
D33: JT1.9, R5.1, U1.D33 (IO33)
D34: JT1.12, R8.1, U1.D34 (IO34)
D35: JT1.11, R7.1, U1.D35 (IO35)
D36: JT1.14, R10.1, U1.D36 (VP-OI36)
D39: JT1.13, R9.1, U1.D39 (VN-IO39)
FOGLIGHTS: IC3.13 (O4), JP18.2, JP19.2
GND: C1.-, C4.1, IC2.8 (GND), IC3.8 (GND), IC4.1 (GND), IC4.4 (IN_GND), JP1.1, JP2.1, JP3.1, JP4.1, JP5.1, JP6.1, JP7.1, JP8.1, JP9.1, JP10.1, JP11.1, JP12.1, JP14.1, JP15.1, JP15.7, JP34.1, JPIN.1, JT1.2, JT2.2, R18.A, U1.GND@1 (GND), U1.GND@2 (GND), U$1.IN-.1, U$1.IN-.2, U$1.OUT-.1, U$1.OUT-.2, X1.1
HEADLIGHTS: IC2.14 (O3), JP27.2, JP28.2
INDICATOR_L: IC3.15 (O2), JP16.2, JP20.4, R27.1
INDICATOR_R: IC3.14 (O3), JP17.2, JP20.2, R30.1
unnamed: IC4.3 (IN_R), IC4.5 (IN_L), R18.S
unnamed: R11.1, R12.1, R18.E
unnamed: JP1.3, JP2.3, R1.2
unnamed: JP13.6, R28.2
unnamed: JP2.4, JP3.3, JP4.3, R2.2
unnamed: JP5.3, JP6.3, R3.2
unnamed: JP6.4, JP7.3, JP8.3, R4.2
unnamed: JP9.3, JP10.4, R5.2
unnamed: D1.C, JT1.1, U1.VIN
unnamed: JP10.3, R6.2
unnamed: JP11.3, R7.2
unnamed: JP11.4, JP12.3, R8.2
unnamed: JP13.4, R30.2
unnamed: JPIN.3, R10.2
unnamed: JP13.2, R27.2
unnamed: JP13.1, JP32.2
unnamed: C4.2, JT1.15, U1.EN
unnamed: JP13.3, JP33.2
unnamed: D3.C, U$1.IN+.1, U$1.IN+.2
unnamed: D3.A, X1.2
unnamed: JP14.3, R9.2
unnamed: JP34.3, R13.2
REVERSING: IC3.12 (O5), JP20.1, JP32.1
ROOFLIGHTS: IC3.11 (O6), JP21.2, JP22.2
SHAKER: D2.A, IC2.10 (O7), IC2.11 (O6), IC2.12 (O5), JP29.2
SIDELIGHTS: IC3.10 (O7), JP20.6, JP23.2, JP24.2, JP33.1
TAILLIGHTS: IC3.16 (O1), JP20.3, R28.1

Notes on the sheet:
Speaker 1
Speaker 2
13 CH1 Steering
12 CH2 Shifting
14 CH3 Throttle
27 CH4 Pot
33 ESC Output
32 Upper Brake Lights
35 IN1
34 IN2
Serial Rx SBUS IBUS PPM
DAC 1 & 2 Mixer Resistors
Audio amplifier
Volume Potentiometer
5V power supply for amplifier & LED
Battery input 7.0 - 12.6V
SMD Board for 30 pin ESP32 V1.2 - PHL
Shaker motor
Headlights
Foglights
Indicator L
Indicator R
Roof lights
Side lights
Connector for TAMIYA trailer light set 56502
Rear lights
ESP32 RC Sound & Light Controller https://github.com/TheDIYGuy999/Rc_Engine_Sound_ESP32
Never connect LED directly, always use a matching series resistor!
Beacon 2
Beacon 1
Cabin lights
Pay attention to correct polarity!
Max. input signal voltage = 3.3V!
Changelog V1.2: - C4 added (solving upload issues) - switch mode regulator instead of 7805 - LCD connector - TAMIYA or TheDIYGuy999 pinout selectable for trailer connector - Sidelights pin in JP20 - 5V to +V jumper - Neopixel connector
WARNING!! adjust 5V supply on the trim pot BEFORE soldering step down converter to the PCB!!
SPI LCD dashboard
Add 5V supply jumper, if no ESC with BEC is connected!
39 IN3
15 CH7 Ext

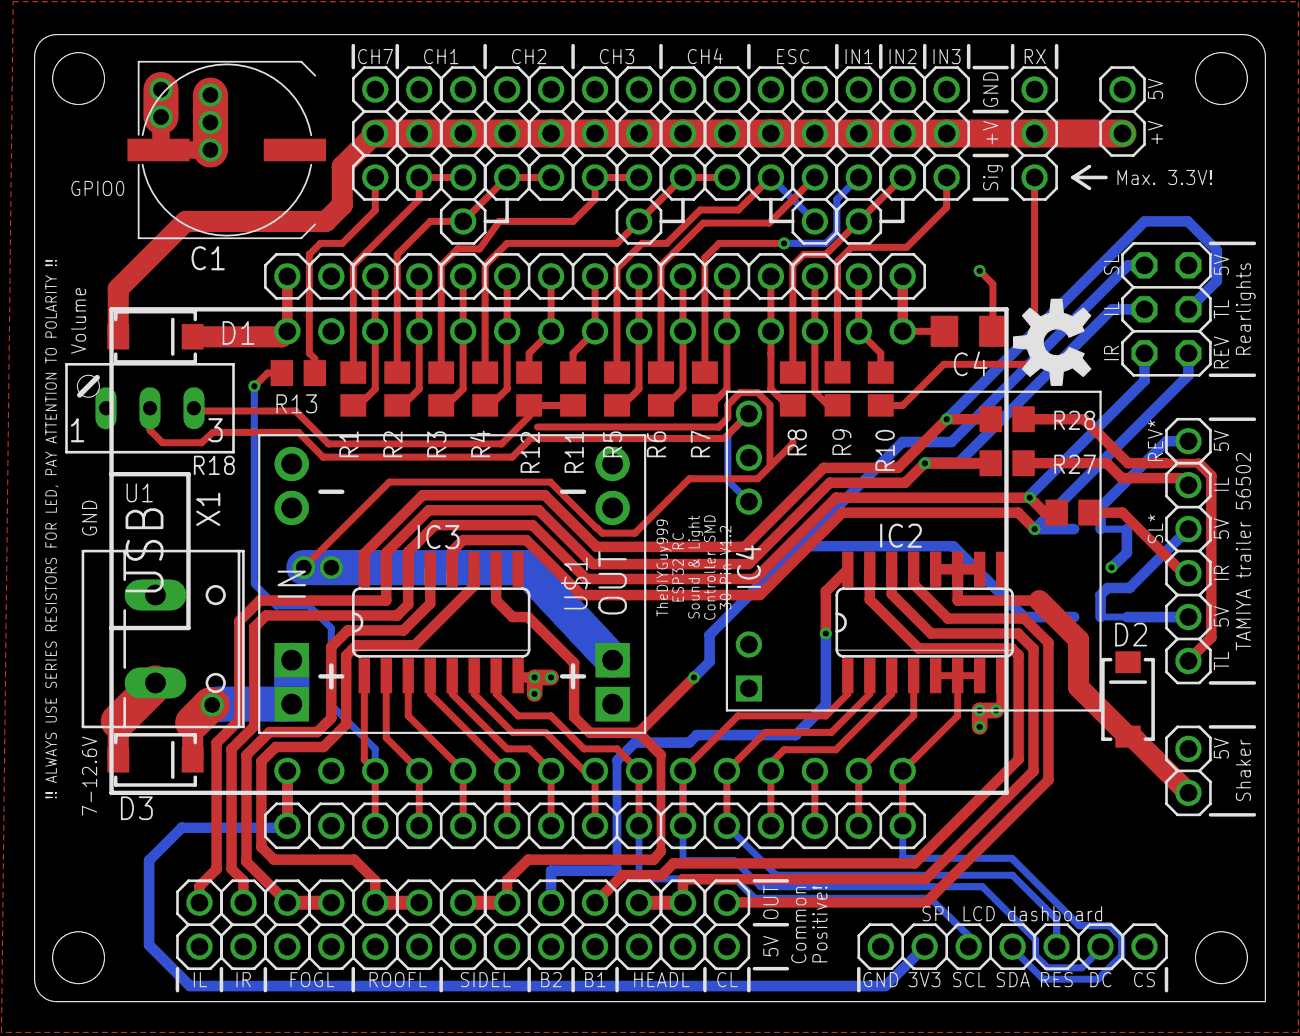
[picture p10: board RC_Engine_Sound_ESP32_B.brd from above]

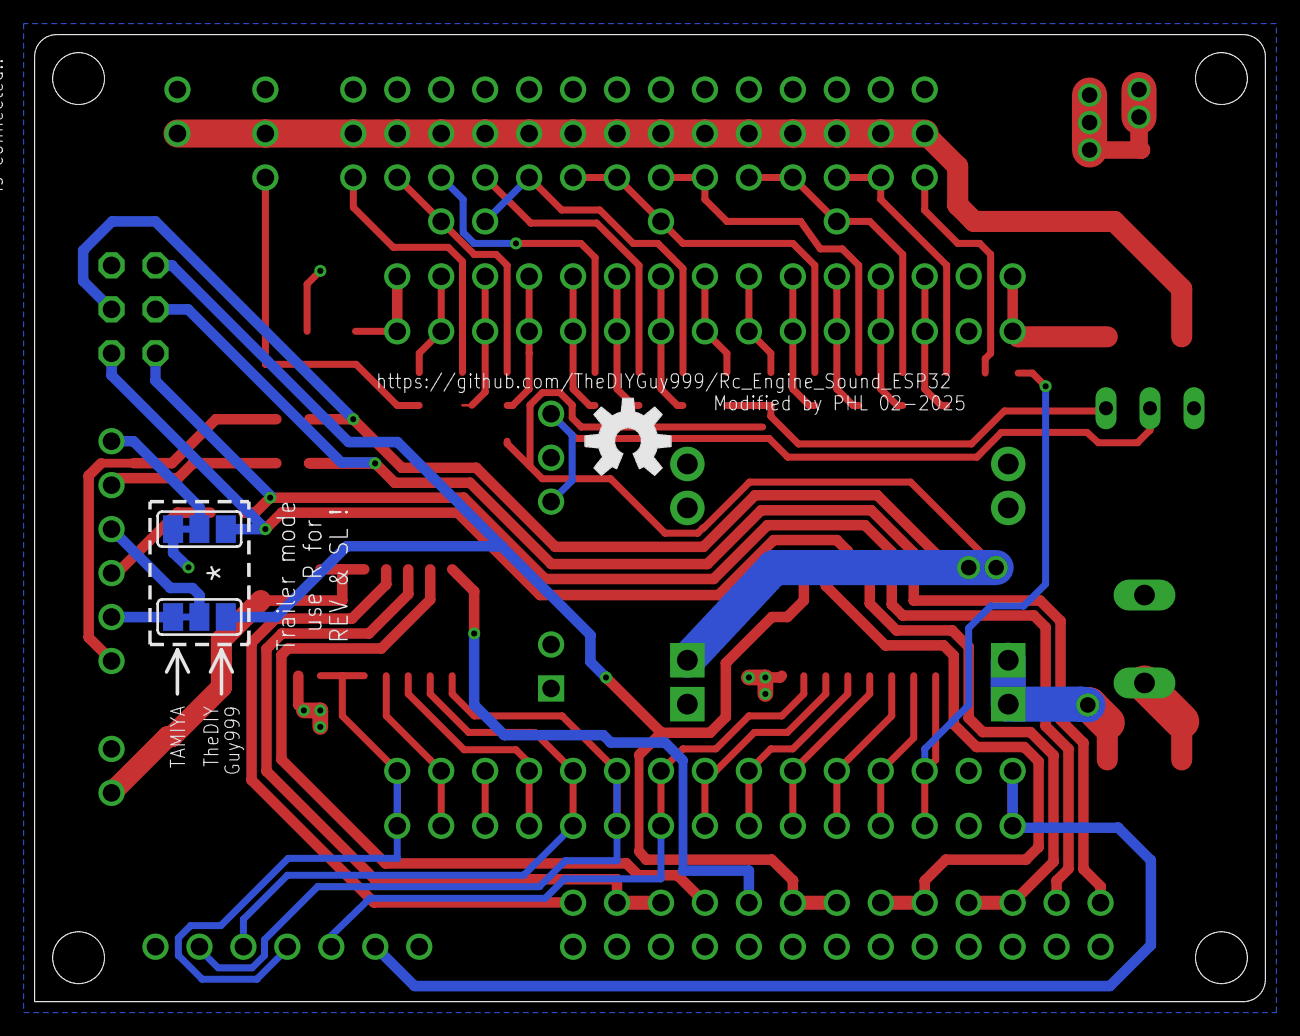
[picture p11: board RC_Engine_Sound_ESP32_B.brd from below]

Board: 2 copper layers, 71.1 x 55.9 mm, 67 parts (3 on the bottom side), 63 nets.

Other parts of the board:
LOGO2: OSHW-LOGOM; OSHW-LOGO-M

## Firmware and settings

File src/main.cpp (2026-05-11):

//
// ESP32_RC_Controler : RC Controler with engine sound
//
// PHL025 : 2025..

// SHIFT + ALT + F : Format document
//
// Ctrl K + Ctrl j: UnFold
// Ctrl K + Ctrl 0: fold all levels (namespace, class, method, and block)
// Ctrl K + Ctrl 1: namespace / @Component(For Angular)
// Ctrl K + Ctrl 2: class / methods
// Ctrl K + Ctrl 3: methods / blocks
// Ctrl K + Ctrl 4: blocks / inner blocks
// Ctrl K + Ctrl [ or ]: current cursor block

/* TYPES
1 byte  : bool, byte, char, unsigned char, int8_t, uint8_t
2 bytes : short, int16_t, uint16_t
4 bytes : int, long, unsigned int, unsigned long, int32_t, uint32_t
8 bytes : long long, unsigned long long, int34_t, uint64_t
4 bytes : float,
8 bytes : double
*/

#include "main.h"

//#include "my_setup/TFT_eSPI_Setup.h"

// Local functions
void Task1code(void *pvParameters);
void setupMcpwm();
void setupEEprom();
void mcpwmOutput();
void outputUpdate();
void SerialDebug(uint32_t cur_ms, uint32_t _last_proccess);
#if defined STD_DASHBOARD or defined FREVIC_DASHBOARD
void updateDashboard();
#endif
// void TriggerSet();
void SoundTriggerSet();

// =======================================================================================================
// PPM Functions
// =======================================================================================================
#pragma region PPM_FUNCTIONS
#ifdef PPM_COMMUNICATION
// =======================================================================================================
// PPM Signal INTERRUPT
// =======================================================================================================
// Interrupt call by PPM digital pin rising edge
void IRAM_ATTR IT_Signal_Ppm()
{
	it_count++;
	rx_data->IT_Ppm(micros());
}

#endif
#pragma endregion PPM_FUNCTIONS

// =======================================================================================================
// Setup
// =======================================================================================================

/// @brief EEPROM Setup
void setupEEprom()
{
#ifdef EEPROM_SIZE
//#if defined ERASE_EEPROM_ON_BOOT
//	romData.Reset(EEPROM_SIZE, 0);
//#endif
	// Init with default values, if eeprom_id changed
	romData.Init(eeprom_id);
	// Read settings from Eeprom
	romData.Read();	
	romData.Debug();
#endif
};

/// @brief Setup program
void setup()
{
	// Watchdog timers need to be disabled, if task 1 is running without delay(1)
	disableCore0WDT();
	// disableCore1WDT(); // Core 1 WDT can stay enabled TODO

	// Setup RTC (Real Time Clock) watchdog
	rtc_wdt_protect_off(); // Disable RTC WDT write protection
	rtc_wdt_set_length_of_reset_signal(RTC_WDT_SYS_RESET_SIG, RTC_WDT_LENGTH_3_2us);
	rtc_wdt_set_stage(RTC_WDT_STAGE0, RTC_WDT_STAGE_ACTION_RESET_SYSTEM);
	rtc_wdt_set_time(RTC_WDT_STAGE0, 30000); // set 10s timeout
	rtc_wdt_enable();						 // Start the RTC WDT timer
											 // rtc_wdt_disable();            // Disable the RTC WDT timer
	rtc_wdt_protect_on();					 // Enable RTC WDT write protection

	// Set pin modes
	pinMode(COMMAND_RX, INPUT_PULLDOWN);

	// Serial setup
	Serial.begin(115200, SERIAL_8N1, DEBUG_RX, DEBUG_TX); // USB serial (for DEBUG) Mode, Rx pin (99 = not used), Tx pin
	delay(1000);										  // Give serial port/connection some time to get ready
	Serial.printf("\n");
	Serial.printf("**************************************************************************************************\n");
	Serial.printf("* Setup\n");
	Serial.printf("**************************************************************************************************\n");
	Serial.printf("* XTAL Frequency: %i MHz, CPU Clock: %i MHz, APB Bus Clock: %i Hz\n", getXtalFrequencyMhz(), getCpuFrequencyMhz(), getApbFrequency());
	Serial.printf("* Internal RAM size: %i Byte, Free: %i Byte\n", ESP.getHeapSize(), ESP.getFreeHeap());
	for (uint8_t coreNum = 0; coreNum < 2; coreNum++)
	{
		uint8_t resetReason = rtc_get_reset_reason(coreNum);
		if (resetReason <= (sizeof(RESET_REASONS) / sizeof(RESET_REASONS[0])))
		{
			Serial.printf("* Core %i reset reason: %i: %s\n", coreNum, rtc_get_reset_reason(coreNum), RESET_REASONS[resetReason - 1]);
		}
	}
	lastloop_ms = millis();
	Serial.printf("* File : %s\n", __FILE__);
	Serial.printf("* - Compiled : %s at %s \n", __DATE__, __TIME__);
	Serial.printf("* Configuration : %s\n", CONFIGURATION);
	//
	Serial.printf("* Setup MCPWM \n");
	setupMcpwm();
#ifdef PWM_COMMUNICATION
	Serial.printf("* - PWM1 to PWM4, Not avalaible if RX_PWM Mode\n");
#else
	Serial.printf("* - PWM 1 : Ch[%i]\n", PwmOutputChannel[1]);
	Serial.printf("* - PWM 2 : Ch[%i]\n", PwmOutputChannel[2]);
	Serial.printf("* - PWM 3 : Ch[%i]\n", PwmOutputChannel[3]);
	Serial.printf("* - PWM 4 : Ch[%i]\n", PwmOutputChannel[4]);
#endif
	Serial.printf("* - PWM 5 : Ch[%i]\n", PwmOutputChannel[5]);
	Serial.printf("* - PWM 6 : Ch[%i]\n", PwmOutputChannel[6]);

	// ESC contiguration
#ifdef ESC1_DRIVER // ESC 1
	esc_1 = new EscDriver(1, MCPWM_UNIT_1, MCPWM_TIMER_0, MCPWM0A, MCPWM0B, ESC1_PIN1, ESC1_PIN2, ESC1_FREQUENCY);
	Serial.printf("* Setup ESC 1 : Ch[%i], Unit %i, timer %i, Pin %i - %i, %iHz at %x\n", ESC1_CH, MCPWM_UNIT_1, MCPWM_TIMER_0, ESC1_PIN1, ESC1_PIN2, ESC1_FREQUENCY, esc_1);
	esc_1->setPwm(ESC1_DRAGBRAKE_DUTY, ESC1_DRAGBRAKE_DUTY);
#endif
#ifdef ESC2_DRIVER // ESC 2
	esc_2 = new EscDriver(2, MCPWM_UNIT_1, MCPWM_TIMER_1, MCPWM1A, MCPWM1B, ESC2_PIN1, ESC2_PIN2, ESC2_FREQUENCY);
	Serial.printf("* Setup ESC 2 : Ch[%i], Unit %i, timer %i, Pin %i - %i, %iHz at %x\n", ESC2_CH, MCPWM_UNIT_1, MCPWM_TIMER_1, ESC2_PIN1, ESC2_PIN2, ESC2_FREQUENCY, esc_2);
	esc_2->setPwm(ESC2_DRAGBRAKE_DUTY, ESC2_DRAGBRAKE_DUTY);
#endif
#ifdef ESC3_DRIVER // ESC 3
	esc_3 = new EscDriver(3, MCPWM_UNIT_1, MCPWM_TIMER_2, MCPWM2A, MCPWM2B, ESC3_PIN1, ESC3_PIN2, ESC3_FREQUENCY);
	Serial.printf("* Setup ESC 3 : Ch[%i], Unit %i, timer %i, Pin %i - %i, %iHz at %x\n", ESC3_CH, MCPWM_UNIT_1, MCPWM_TIMER_2, ESC3_PIN1, ESC3_PIN2, ESC3_FREQUENCY, esc_3);
	esc_3->setPwm(ESC3_DRAGBRAKE_DUTY, ESC3_DRAGBRAKE_DUTY);
#endif
	// Once write with the "normal" way, the write registers directly according to: https://forum.arduino.cc/t/esp32-dacwrite-ersetzen/653954/5
	// all further writes are done directly in the register since
	// it's much faster
	dacWrite(DAC1, 128);
	dacWrite(DAC2, 128);

	// Task 1 setup (running on core 0)
	/*
	TaskHandle_t Task1;
	// Create a task that will be executed in the Task1code() function, with priority 1 and executed on core 0
	xTaskCreatePinnedToCore(
		Task1code, 		// Task function
		"Task1",   		// name of task
		8192,      		// Stack size of task (8192)
		//NULL,			// parameter of the task
		(void*)&mtVariables,	// parameter : struct for data exchange
		1,         		// priority of the task (1 = low, 3 = medium, 5 = highest)
		&Task1,    		// Task handle to keep track of created task
		0);        		// pin task to core 0
	*/

	// Refresh sample intervals (important, because MAX_RPM_PERCENTAGE was probably changed above)
	maxSampleInterval = 4000000 / sampleRate;
	minSampleInterval = 4000000 / sampleRate * 100 / MAX_RPM_PERCENTAGE;
	masterVolume = 50;

	// Interrupt timer for variable sample rate playback
	variableTimer = timerBegin(0, 20, true);						   // timer 0, MWDT clock period = 12.5 ns * TIMGn_Tx_WDT_CLK_PRESCALE -> 12.5 ns * 20 -> 250 ns = 0.25 us, countUp
	timerAttachInterrupt(variableTimer, &variablePlaybackTimer, true); // edge (not level) triggered
	timerAlarmWrite(variableTimer, variableTimerTicks, true);		   // autoreload true
	timerAlarmEnable(variableTimer);								   // enable

	// Interrupt timer for fixed sample rate playback
	fixedTimer = timerBegin(1, 20, true);						 // timer 1, MWDT clock period = 12.5 ns * TIMGn_Tx_WDT_CLK_PRESCALE -> 12.5 ns * 20 -> 250 ns = 0.25 us, countUp
	timerAttachInterrupt(fixedTimer, &fixedPlaybackTimer, true); // edge (not level) triggered
	timerAlarmWrite(fixedTimer, fixedTimerTicks, true);			 // autoreload true
	timerAlarmEnable(fixedTimer);								 // enable

	Serial.printf("* Setup communication :\n");
#if defined CRSF_COMMUNICATION
	// CRSF Communication
	rx_data = new RxCrsf(RX_CHANNELS, channelFailSafe, channelIntregrator, channelReversed);
	Serial.printf("* - CRSF mode, %i channels, error code : %i\n", rx_data->getNbChannels(), rx_data->error);

#elif defined SBUS_COMMUNICATION
	// SBUS Communication
	rx_data = new RxSbus(RX_CHANNELS, channelFailSafe, channelIntregrator, channelReversed);
	Serial.printf("* - SBUS mode, %i channels, error code : %i\n", rx_data->getNbChannels(), rx_data->error);

//#elif defined SBUS_COMMUNICATION_LOCAL
	// SBUS Communication - Local (Old test)
/*
	rx_data = new RxBase(RX_CHANNELS, channelFailSafe, channelIntregrator, channelReversed);
	if (MAX_RPM_PERCENTAGE > maxSbusRpmPercentage)
		MAX_RPM_PERCENTAGE = maxSbusRpmPercentage;				// Limit RPM range
	sBus.begin(COMMAND_RX, COMMAND_TX, sbusInverted, sbusBaud); // begin SBUS communication with compatible receivers

	sbusInit = false;
	Serial.printf("Initializing SBUS LOCAL (sbusInverted = %s, needs to be true for most standard radios) ...\n", sbusInverted ? "true" : "false");
	Serial.printf("(Make sure radio and receiver are connected, turned on, bound and configured for SBUS output.)\n");
	while (!sbusInit)
	{
		readSbusCommands(micros()); // SBUS communication (pin 36)
		// indicatorL.flash(70, 75, 500, 3); // Show 3 fast flashes on indicators!
		// indicatorR.flash(70, 75, 500, 3);
		rtc_wdt_feed(); // Feed watchdog timer
	}
	Serial.printf("... SBUS initialization succesful!\n");
*/

#elif defined PPM_COMMUNICATION
	// PPM Mode
	// if (MAX_RPM_PERCENTAGE > maxPpmRpmPercentage)
	//   MAX_RPM_PERCENTAGE = maxPpmRpmPercentage;						 	// Limit RPM range
//#ifdef PPM_LOCAL	
	Serial.printf("* Configuration\n");
	for (int i = 0; i <= MAX_CHANNELS; i++)
	{
		Serial.printf("Ch[%i]: rev %i, fs %i\n", i, channelReversed[i], channelFailSafe[i]);
	}
	//Serial.printf("* Setup PPM Communication\n");
	rx_data = new RxPpm(RX_CHANNELS, 1, channelFailSafe, channelIntregrator, channelReversed);
	Serial.printf("* - Setup PPM Communication, attach interrupt \n");
	//attachInterrupt(digitalPinToInterrupt(COMMAND_RX), IT_Signal_Ppm, RISING); // begin PPM communication with compatible receivers
	attachInterrupt(digitalPinToInterrupt(COMMAND_RX), IT_Signal_Ppm, FALLING); // begin PPM communication with compatible receivers
	// attachInterrupt(GPIO_NUM_36, PpmIT, RISING); 	// begin PPM communication with compatible receivers
	// RISING : Déclenché lors d'une transition de LOW à HIGH.
    // FALLING : Déclenché lors d'une transition de HIGH à LOW.
    // CHANGE : Déclenché lors de tout changement d'état.
    // LOW : Déclenché lorsque la broche reste à LOW.
    // HIGH : Déclenché lorsque la broche reste à HIGH.
//#else
	// PPM Inside RxPpm class
	//rx_data = new RxPpm(RX_CHANNELS, 1, channelFailSafe, channelIntregrator, channelReversed);
	//rx_data->attachInterrupts();

//#endif

#elif defined PWM_COMMUNICATION
	// PWM Mode
	rx_data = new RxPwm(RX_CHANNELS, PWM_PINS, PWM_CHANNELS, channelFailSafe, channelIntregrator, channelReversed);
	rx_data->attachInterrupts();
	Serial.printf("* - PWM mode (GPIO ISR), %i channels, error code : %i\n", rx_data->getNbChannels(), rx_data->error);

#else
	// No Mode
	rx_data = new RxBase(RX_CHANNELS, channelFailSafe, channelIntregrator, channelReversed);
	Serial.printf("* - Error : No communication mode selected\n");

#endif // Communication mode

	// RX Channel triggers
	// trigger default values are (1800, 500, 1200, 500, 50)
	rx_data->channel[STEERING].trigger.setLevel(1600, 250, 1400, 250, 50);
	rx_data->channel[2].trigger.setLevel(1800, 1000, 1200, 1000, 50);

	// Leds (Use one timer by output, Timer 0,1 : reserved, use 2..15)
	leds = new Outputs();
	// for (int i = 0; i < OUTPUTS_MAX; i++)
	//{
	//	leds[i] = statusLED(false);
	//	leds[i].begin(OUTPUT_PINS[i], i+2, 20000);	// Timers 2 to 14
	// }
	// indicatorL.begin(2, 2, 20000);			// Indicator_L, Timer 2, 20kHz
	// indicatorR.begin(4, 3, 20000);			// Indicator_R, Timer 2, 20kHz
	// shakerMotor.begin(23, 13, 20000); 	// Shaker motor, Timer 13, 20kHz

	// EEPROM Setup
	setupEEprom();

#if defined STD_DASHBOARD or defined FREVIC_DASHBOARD or defined NAVY_DASHBOARD
	// Dashboard setup
	Serial.printf("* Setup DASHBOARD :\n");
	Serial.printf("* - Pins 18 (sidelights), 19 (beacon2), 21 (beacon1), 23 (shaker) are not usable for Outputs !\n");
	//Serial.printf("-------------------------------------\n");
	dashboard.init(TFT_ROTATION);	//(dashRotation);
	//dashboard.init(3);	//(dashRotation);
	Serial.printf("* -> Dashboard initialized\n");
	
#endif

	// TCY
	minTcy = 4294967295;
	maxTcy = 0;
	lastLoop_us = micros();

	// End
	//Serial.printf("*\n");
	Serial.printf("* Mémoire libre après allocation: %d bytes\n", esp_get_free_heap_size());
	Serial.printf("* Setup done\n\n");
	Serial.printf("**************************************************************************************************\n");
	Serial.printf("* Loop\n");
	Serial.printf("**************************************************************************************************\n");
}

// =======================================================================================================
// Loop : Main loop
// =======================================================================================================
/// @brief Loop, background cycle
void loop()
{
	bool new_data;
	// Curent ms, us
	uint32_t curTcy;
	uint32_t cur_ms = millis();
	uint32_t cur_us = micros();
	bgdCount++;

	// Running core
	if (coreLoop == -1)
		coreLoop = xPortGetCoreID();
	
	// RX channels update
	rx_data->updateChannels(cur_us);
	// Update
	uint32_t _last_proccess = rx_data->GetLastProccess();
	uint32_t _delta_us = rx_data->timeDiff(cur_us, _last_proccess);
	// New data or 100ms
	new_data = rx_data->Get_NewData();		// Get and reset if true
	if (new_data || (_delta_us > 500000UL)) // New data or Timeout 500ms
	{
		// Data process
		rx_data->processRawChannels(cur_us);
		cpProccess++;
		// Multi switch mixer (Need CRSF / SBUS protocol) - Not tested with PWM/PPM protocol(2026-01)
#ifdef MIX3P
		// Use 'Mix3P.lua', Tested with TX16S / RH3-P (CRSF)
		rx_data->channel[MIX3P].GetMix3P(!rx_data->ready);	//(rx_data->failSafe);
#elif MIX4
		// Use 'Mix4.lua', Tested with TX16S / RH3-P (CRSF)
		rx_data->channel[MIX4].GetMix4(!rx_data->ready);
#endif
		//
		mcpwmOutput(); 	// PWM servo signal output
		// Esc 1
		if (esc_1 != NULL)
		{
			// Ramp managed by ESC (like ATiny85 ESC)
			esc_1->rampAVR(rx_data->channel[ESC1_CH].rx, cur_ms, engineOn);	//, rx_data->ready);	
			//esc_1->update(rx_data->channel[ESC1_CH].rxd, false); 	// Rampe managed by channel[].rxd
			currentPwm = abs(esc_1->getPwm());					 	// [0..100] %
			currentRpm = currentPwm * 5;						 	// [0..500]
		}
		else
		{
			currentPwm = abs(map(rx_data->channel[THROTTLE].rxd, 1000, 2000, -100, 100));
			currentRpm = currentPwm * 5; // [0..500]
		}
		// Esc 2
		if (esc_2 != NULL)
			// esc_2->rampAVR(rx_data->channel[ESC2_CH].rx, cur_ms);	// Rampe managed by ESC
			esc_2->update(rx_data->channel[ESC2_CH].rxd, false); // Rampe managed by channel[].rxd
		// Esc 3
		if (esc_3 != NULL)
			// esc_3->rampAVR(rx_data->channel[ESC3_CH].rx, cur_ms);	// Rampe managed by ESC
			esc_3->update(rx_data->channel[ESC3_CH].rxd, false); // Rampe managed by channel[].rxd
		//
		// IEC Timer
		//
		TON_Pwm_0.TON((currentPwm == 0) && (engineState != STARTING), cur_ms, 20000); 		// 20s
		rxReady = TON_Ready.TON((!rx_data->failSafe), cur_ms, 1000); 		// 1s
		//
		// Engine sound
		//
		if ((rx_data->failSafe || TON_Pwm_0.ton) && engineOn)
			engineOn = false;
		if (rx_data->channel[THROTTLE].rxd > 1600 && !engineOn)		// 1500 + 20%
			engineOn = true;
		//
		// Speed (sample rate) output
		engineSampleRate = map(currentPwm, minPwm, maxPwm, maxSampleInterval, minSampleInterval);
		// Sound trigger
		SoundTriggerSet();
		// Volume adjustment
		VolumeSet();
		// Fader
		// dacOffsetFade(); 	// Move to Task1
	}
	// Output update
	modelOutput(rx_data->channel, leds->channel, rxReady, engineState == STARTING);
	// outputUpdate();			// Output

	// Dashboard control
	#if defined STD_DASHBOARD or defined FREVIC_DASHBOARD
	updateDashboard();
	#elif defined NAVY_DASHBOARD
	dashboard.update(cur_ms);
	//dashboard.update(currentRpm, currentPwm, rxReady, engineState == STARTING);
	#endif

	// Debug chanels
	if (cur_ms > lastloop_ms + 500)
	{
		lastloop_ms = cur_ms;
		debugLine = 1;
	}
	if (debugLine > 0)
		SerialDebug(lastloop_ms, _last_proccess);

	// Loop TCY
	cur_us = micros();
	curTcy = (uint32_t)cur_us - lastLoop_us;
	lastLoop_us = cur_us;
	if (cur_ms > 2000)
	{
		if (curTcy < minTcy)
			minTcy = curTcy;
		if (curTcy > maxTcy)
			maxTcy = curTcy;
	}

	// Feeding the RTC watchtog timer is essential!
	rtc_wdt_feed();
}

// =======================================================================================================
// Task 1
// =======================================================================================================
/// @brief Task1code : Task1 programm
/// @param pvParameters
void Task1code(void *pvParameters)
{
	mtVariables_t *my_var = (mtVariables_t *)pvParameters;
	for (;;)
	{
		// Running core
		if (my_var->coreT1 < 0)
			my_var->coreT1 = xPortGetCoreID();

		// ESC control & low discharge protection
		// #ifdef BOAT_MODE
		//	esc_boat();
		// #else
		//	esc();
		// #endif

		// DAC offset fader
		dacOffsetFade();

		// Engine
		// if (rx_data->rxd_channel[ESC1_CH] > 1750 && !engineOn)
		//	engineOn = true;
		// currentRpm = 50;	//abs(esc_1->getPwm());

		// measure loop time
		// loopTime = loopDuration(); // for debug only

		// Feeding the RTC watchtog timer is essential!
		rtc_wdt_feed(); // TODO, test only
	}
}

// =======================================================================================================
// Outputs
// =======================================================================================================

/// @brief Output update
void outputUpdate()
{
	// outputModel(rx_data->channel, leds->channel);
	return;

	// int l_curPwm = std::abs(currentPwm);
	// l_curPwm = l_curPwm << 1;
	// int l_curPwm = abs(map(currentPwm, -100, 100, -255, 255));
	//  Output / Led 1
	// Led1.set(rx_data->channel[4].trigger.latchLow);
	// led1.set(OUT1_CMD);
	//  Output / Led 2
	// led2.set(OUT2_CMD);
	//  Output / Led 3
	// Led3.set(OUT3_CMD);
	// led_d2.pwm(l_curPwm);
	// led_d4.pwm(255-l_curPwm);

	/*
	// Indicator R [4], pin 'D4'
	if (rx_data->channel[STEERING].trigger.low)
	{
		leds->channel[4].flash(375, 375, 0, 0, 0, 250, 0);
		//leds->flash(4, 375, 375, 0, 0, 0, 250, 0);
		//indicatorR.flash(375, 375, 0, 0, 0, 250, 0);
	}
	else
		leds->channel[4].off(250, 0);
		//leds->off(250, 0);
		//indicatorR.off(250, 0);

	// Indicator L [5], pin 'D2'
	if (rx_data->channel[STEERING].trigger.high)
		leds->channel[5].flash(375, 375, 0, 0, 0, 250, 0);
		//leds->flash(5, 375, 375, 0, 0, 0, 250, 0);
		//indicatorL.flash(375, 375, 0, 0, 0, 250, 0);
	else
		leds->channel[5].off(250, 0);
		//leds->off(250, 0);
		//indicatorL.off(250, 0);
	*/
}

/// @brief Setup MCPWM configuration (CH1 to CH6, CH7)
void setupMcpwm()
{
	// Configure MCPWM parameters
	mcpwm_config_t pwm_config;
	pwm_config.frequency = SERVO_FREQUENCY; // frequency usually = 50Hz, some servos may run smoother @ 100Hz
	pwm_config.cmpr_a = 0;					// duty cycle of PWMxa = 0
	pwm_config.cmpr_b = 0;					// duty cycle of PWMxb = 0
	pwm_config.counter_mode = MCPWM_UP_COUNTER;
	pwm_config.duty_mode = MCPWM_DUTY_MODE_0; // 0 = not inverted, 1 = inverted

#ifndef PWM_COMMUNICATION
	// Set our servo output pins
#ifndef ESC3_DRIVER
	mcpwm_gpio_init(MCPWM_UNIT_0, MCPWM0A, 13); // Set steering as PWM0A
	mcpwm_gpio_init(MCPWM_UNIT_0, MCPWM0B, 12); // Set shifting as PWM0B
	// Configure channels with settings above
	mcpwm_init(MCPWM_UNIT_0, MCPWM_TIMER_0, &pwm_config); // Configure PWM0A & PWM0B
#else
	mcpwm_gpio_init(MCPWM_UNIT_0, MCPWM0A, 15); // Set steering as PWM0A
	// Configure channels with settings above
	mcpwm_init(MCPWM_UNIT_0, MCPWM_TIMER_0, &pwm_config); // Configure PWM0A & PWM0B
#endif
#ifndef ESC2_DRIVER
	mcpwm_gpio_init(MCPWM_UNIT_0, MCPWM1A, 14); // Set xx as PWM1A
	mcpwm_gpio_init(MCPWM_UNIT_0, MCPWM1B, 27); // Set xx as PWM1B
	// Configure channels with settings above
	mcpwm_init(MCPWM_UNIT_0, MCPWM_TIMER_1, &pwm_config); // Configure PWM1A & PWM1B
#endif
#endif // PWM_COMMUNICATION
#ifndef ESC1_DRIVER
	mcpwm_gpio_init(MCPWM_UNIT_0, MCPWM2A, 32); // Set xx as PWM2A
	mcpwm_gpio_init(MCPWM_UNIT_0, MCPWM2B, 33); // Set xx as PWM2B
	// Configure channels with settings above
	mcpwm_init(MCPWM_UNIT_0, MCPWM_TIMER_2, &pwm_config); // Configure PWM2A & PWM2B
#endif
}

/// @brief Set MCPWM outputs (CH1 to CH6, CH7)
void mcpwmOutput()
{
	// Set PWM chanels [1000..2000]
#ifndef PWM_COMMUNICATION
#ifndef ESC3_DRIVER
	// CH1 [1000..2000], Pin 13
	// mcpwm_set_duty_in_us(MCPWM_UNIT_0, MCPWM_TIMER_0, MCPWM_OPR_A, rx_data->_channel[1].rx);
	mcpwm_set_duty_in_us(MCPWM_UNIT_0, MCPWM_TIMER_0, MCPWM_OPR_A, rx_data->channel[PwmOutputChannel[1]].rx);
	// CH2, Pin 12
	// mcpwm_set_duty_in_us(MCPWM_UNIT_0, MCPWM_TIMER_0, MCPWM_OPR_B, rx_data->_channel[2].rx);
	mcpwm_set_duty_in_us(MCPWM_UNIT_0, MCPWM_TIMER_0, MCPWM_OPR_B, rx_data->channel[PwmOutputChannel[2]].rx);
#else
	//  CH1 [1000..2000], Pin 15 (PHL)
	mcpwm_set_duty_in_us(MCPWM_UNIT_0, MCPWM_TIMER_0, MCPWM_OPR_A, rx_data->channel[1].rx);
#endif
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

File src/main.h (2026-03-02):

//
// main.h
//
#ifndef MAIN_H
#define MAIN_H

//
// INCLUDES
//
#pragma region INCLUDE_ZONE
// #include <Arduino.h>
#include <esp_attr.h>
#include "esp32-hal-dac.h"
// For
// #include <WiFi.h>			// For Wifi, ESP-NOW
// #include <WifiEspNow.h>		// For ESP-NOW (wifi communication protocol - Espressif)

// No need to install these, they come with the ESP32 board definition
#include <driver/gpio.h>		// For GPIO
#include <driver/uart.h>		// for UART macro UART_PIN_NO_CHANGE
#include <driver/rmt.h>			// for PWM signal detection
#include <driver/mcpwm.h>		// for servo PWM output
#include <rom/rtc.h>			// for displaying reset reason
#include <soc/rtc_wdt.h>		// for watchdog timer
#include <string.h>

// Objects
#include "objects/global.h"
//
#include "objects/receiver/rxBase.h"		// Rx object, base - PHL
#include "objects/receiver/rxPpm.h"			// Rx object, PPM input mode - PHL
#include "objects/receiver/rxPwm.h"			// Rx object, PMM input mode - PHL
#include "objects/receiver/rxSbus.h"		// Rx object, SBUS - PHL
#include "objects/receiver/rxCrsf.h"		// Rx object, CRSF - PHL
#include "objects/receiver/chTrigger.h"		// Trigger - PHL
//
#include "objects/controler/escDriver.h"	// ESC Driver object, type RZ7886 - PHL
#include "objects/controler/iecTimer.h"		// IEC Timer - PHL
#include "objects/controler/outputs.h"		// Outputs - PHL
//
#include "objects/soundPlayer.h"			// Sound player - PHL
#include "objects/eepromData.h"				// EEPROM Data ()

// Configuration : model
#include "0_Model.h"

// Ext_src : TheDIYGuy999 source code
// SBUS (Test idem RC_Engine_Sound_V9.13)
#if defined EMBEDDED_SBUS
#include "src_ext/sbus.h" // For SBUS interface
#endif

// Standard dashboard (TheDIYGuy999 / RC_Engine_Sound_V9.13)
#if defined STD_DASHBOARD		
//#include "tft_setup.h"		// For TFT display configuration (TFT_eSPI library)
#include "src_ext/dashboard_std.h"
Dashboard dashboard;
#define MAX_REAL_SPEED 120 // km/h, for speedometer calibration

// Frevic dashboard (TheDIYGuy999 / RC_Engine_Sound_V9.13)
#elif defined FREVIC_DASHBOARD
//#include "tft_setup.h"		// For TFT display configuration (TFT_eSPI library)
#include "src_ext/dashboard_frevic.h"
Dashboard dashboard;
#define MAX_REAL_SPEED 120 		// km/h, for speedometer calibration

#elif defined NAVY_DASHBOARD
//#include "tft_setup.h"		// For TFT display configuration (TFT_eSPI library)
#include "objects/dashboard_navy.h"
Dashboard dashboard;
#define MAX_REAL_SPEED 60 		// km/h, for speedometer calibration

#endif

// For 0.96 or 1.3 inch display rotation
#ifdef ST7789_DRIVER
#define TFT_ROTATION 0		// 0, 1, 2 or 3 (0 = portrait, connector on top, 1 = landscape, connector on right, 2 = portrait, connector on bottom, 3 = landscape, connector on left)
#else
#define TFT_ROTATION 3		// 0, 1, 2 or 3 (0 = portrait, connector on top, 1 = landscape, connector on right, 2 = portrait, connector on bottom, 3 = landscape, connector on left)
#endif

#pragma endregion INCLUDE_ZONE

//
// Datas
//

// Battery
#define BATTERY_DETECT_PIN 39 // Voltage divider resistors connected to pin "VN & GND"

// Serial DEBUG pins -----
#define DEBUG_RX UART_PIN_NO_CHANGE // 99 is just a dummy, because the "RX0" pin (GPIO3) is used for the headlights and causing issues, if rx enabled! -1 (3 headlights)
#define DEBUG_TX 1					// The "RX0" is on pin 1
uint32_t lastloop_ms = 0;

// These are used to print the reset reason on startup
const char *RESET_REASONS[] = {"POWERON_RESET", "NO_REASON", "SW_RESET", "OWDT_RESET", "DEEPSLEEP_RESET", "SDIO_RESET", "TG0WDT_SYS_RESET", "TG1WDT_SYS_RESET", "RTCWDT_SYS_RESET", "INTRUSION_RESET", "TGWDT_CPU_RESET", "SW_CPU_RESET", "RTCWDT_CPU_RESET", "EXT_CPU_RESET", "RTCWDT_BROWN_OUT_RESET", "RTCWDT_RTC_RESET"};

// ESP32 : Eviter les allocations dynamiques
// Dynamic definitions
EscDriver *esc_1 = NULL; // ESC1, Driver type RZ7886
EscDriver *esc_2 = NULL; // ESC2, Driver type RZ7886
EscDriver *esc_3 = NULL; // ESC3, Driver type RZ7886
// Static definitions
/*
#ifdef ESC1_DRIVER 	// ESC Driver
	EscDriver esc_1(1, MCPWM_UNIT_1, MCPWM_TIMER_0, MCPWM0A, MCPWM0B, ESC1_PIN1, ESC1_PIN2, ESC1_FREQUENCY);
#endif
#ifdef ESC2_DRIVER
	EscDriver esc_2(2, MCPWM_UNIT_1, MCPWM_TIMER_1, MCPWM1A, MCPWM1B, ESC2_PIN1, ESC2_PIN2, ESC2_FREQUENCY);
#endif
#ifdef ESC3_DRIVER
	EscDriver esc_3(3, MCPWM_UNIT_1, MCPWM_TIMER_2, MCPWM2A, MCPWM2B, ESC3_PIN1, ESC3_PIN2, ESC3_FREQUENCY);
#endif
*/

//
// Outputs
//
Outputs *leds = NULL;
// Output 	Leds[OUTPUTS];
// Output	led1(PIN_OUT1);
// Output	led2(PIN_OUT2);
// Output	Led3(PIN_OUT2);

// Test
// statusLED indicatorL(false);
// statusLED indicatorR(false);
// statusLED shakerMotor(false);

//
// Tempos
//
IecTimer TON_Pwm_0;
IecTimer TON_Ready;
bool rxReady = false;

//
// Triggers -> Move to receiver->channel[]
//
/*
ChTrigger trigCh2(1800, 1000, 1200, 1000, 50);
ChTrigger trigCh3;		    // use default values (1800, 500, 1200, 500, 50)
ChTrigger trigCh4;			// use default values (1800, 500, 1200, 500, 50)
ChTrigger trigCh5(1800, 500, 1200, 250, 50);
*/
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

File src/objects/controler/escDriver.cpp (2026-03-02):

//
// EscDriver.cpp : EscDriver class, Driver for RC ESC
//
// Author : PHL @2025

#include <Arduino.h>		// for map, min
//#include "stdint.h"
//#include <driver/mcpwm.h> 	// for servo PWM output
#include <WString.h>

// ESC 
#include "escDriver.h"

// Class definition (methodes)

 /// @brief Construct a new EscDriver object, with parameters
 /// @param number ESC number
 /// @param unit MCPWM unit, MCPWMunit__0 or MCPWMunit__1
 /// @param timer MCPWM timer, MCPWMunit__0 or MCPWMunit__1
 /// @param chanelA MCPWM operator, for chanel A (MCPWM0A or MCPWM0B)
 /// @param chanelB MCPWM operator, for chanel B (MCPWM0A or MCPWM0B)
 /// @param pinA PWM pin number, chanel A
 /// @param pinB PWM pin number, chanel B
 /// @param frequency PWM frequency (Hz), 500 Hz is recommended.
EscDriver::EscDriver(int number, mcpwm_unit_t unit, mcpwm_timer_t timer, mcpwm_io_signals_t chanelA, mcpwm_io_signals_t chanelB, int pinA, int pinB, uint32_t frequency)
{
	// Datas
	number_ = number;
	unit_ = unit;
	timer_ = timer;
	chanelA_ = chanelA;
	chanelB_ = chanelB;
	drag_brake_ = 10;
	// 1. set our ESC output pin
	// mcpwm_gpio_init(MCPWMunit__1, MCPWM0A, RZ7886_PIN1); // Set RZ7886 pin 1 as PWM0A
	// mcpwm_gpio_init(MCPWMunit__1, MCPWM0B, RZ7886_PIN2); // Set RZ7886 pin 2 as PWM0B
	mcpwm_gpio_init(unit_, chanelA_, pinA); // Set RZ7886 pin 1 as PWM0A
	mcpwm_gpio_init(unit_, chanelB_, pinB); // Set RZ7886 pin 2 as PWM0B

	// 2. configure MCPWM parameters
	mcpwm_config_t pwm_config;
	pwm_config.frequency = frequency; // frequency
	pwm_config.cmpr_a = 0;			  // duty cycle of PWMxa = 0
	pwm_config.cmpr_b = 0;			  // duty cycle of PWMxb = 0
	pwm_config.counter_mode = MCPWM_UP_COUNTER;
	pwm_config.duty_mode = MCPWM_DUTY_MODE_0; // 0 = not inverted, 1 = inverted

	// 3. configure channels with settings above
	// mcpwm_init(MCPWMunit__1, MCPWMtimer__0, &pwm_config); // Configure PWM0A & PWM0B
	mcpwm_init(unit_, timer_, &pwm_config); // Configure PWM0A & PWM0B
}


/// @brief Destroy the EscDriver object.
EscDriver::~EscDriver()
{
	setPwm(0, 0);
}


/// @brief Set PWM for both chanels
/// @param pwmA PWM value, chanel A, Forward [0..255]
/// @param pwmB PWM value, chanel B, Reverse [0..255]
void EscDriver::setPwm(uint8_t pwmA, uint8_t pwmB)
{
	if (pwmA > 0 && pwmB == 0)	// Forward
	{
		mcpwm_set_signal_high(unit_, timer_, MCPWM_OPR_A); 		// Pin A high
		mcpwm_set_duty(unit_, timer_, MCPWM_OPR_B, pwmA);
		mcpwm_set_duty_type(unit_, timer_, MCPWM_OPR_B, MCPWM_DUTY_MODE_1); // MCPWM_DUTYmode__1 = inverse PWM mode, high, if 0% PWM
	}
	if (pwmB > 0 && pwmA == 0)	// Reverse
	{
		mcpwm_set_signal_high(unit_, timer_, MCPWM_OPR_B); 		// Pin B high
		mcpwm_set_duty(unit_, timer_, MCPWM_OPR_A, pwmB);
		mcpwm_set_duty_type(unit_, timer_, MCPWM_OPR_A, MCPWM_DUTY_MODE_1); // MCPWM_DUTYmode__1 = inverse PWM mode, high, if 0% PWM
	}
	if (pwmA == pwmB)
	{
		// Both pins pwm @ the same time = variable drag brake
		mcpwm_set_duty(unit_, timer_, MCPWM_OPR_A, pwmA); 		// RZ7886_DRAGBRAKE_DUTY);
		mcpwm_set_duty(unit_, timer_, MCPWM_OPR_B, pwmB); 		// RZ7886_DRAGBRAKE_DUTY);
		mcpwm_set_duty_type(unit_, timer_, MCPWM_OPR_A, MCPWM_DUTY_MODE_0);
		mcpwm_set_duty_type(unit_, timer_, MCPWM_OPR_B, MCPWM_DUTY_MODE_0);
	}
}


/// @brief Update ESC output
/// @param rx_value Rx value (500..2000)
/// @param debug Enable printf for debug
void EscDriver::update(uint16_t rx_value, bool debug)
{
	uint16_t escSignal;
	uint8_t motorDriverDuty;
	
	escSignal = rx_value;
	//
	if (escSignal > neutre_max_)		// 1520
	{ 	// Forward
		motorDriverDuty = min(map(escSignal, neutre_max_, 2000, out_min_, out_max_), 100L);
		setPwm(motorDriverDuty, 0);
		motorPwm_ = motorDriverDuty;
	}
	else if (escSignal < neutre_min_)	// 1480
	{ 	// Reverse
		motorDriverDuty = min(map(escSignal, neutre_min_, 1000, out_min_, out_max_), 100L);
		setPwm(0, motorDriverDuty);
		motorPwm_ = (int8_t)(0-motorDriverDuty);
	}
	else
	{	// Neutral
		motorDriverDuty = 0; 	// Just for cosmetic reasons in ESC_DEBUG
		motorPwm_ = 0;
		// Both pins pwm @ the same time = variable drag brake
		setPwm(drag_brake_, drag_brake_);
	}
}


/// @brief Update ESC output, whith rampe up/down (NOK)
/// @param rx_value Rx value (500..2000)
/// @param debug Enable printf for debug
void EscDriver::updateRamp(uint16_t rx_value, bool debug)
{
	uint16_t escSignal;
	uint8_t motorDriverDuty;
	
	escSignal = rx_value;
	//
	if (escSignal > 1520)
	{ 	// Forward
		motorDriverDuty = min(map(escSignal, 1500, 2000, 0, 100), 100L);
		setPwm(motorDriverDuty, 0);
		motorPwm_ = motorDriverDuty;
	}
	else if (escSignal < 1480)
	{ 	// Reverse
		motorDriverDuty = min(map(escSignal, 1500, 1000, 0, 100), 100L);
		setPwm(0, motorDriverDuty);
		motorPwm_ = (int8_t)(0-motorDriverDuty);
	}
	else
	{	// Neutral
		motorDriverDuty = 0; 	// Just for cosmetic reasons in ESC_DEBUG
		motorPwm_ = 0;
		// Both pins pwm @ the same time = variable drag brake
		setPwm(drag_brake_, drag_brake_);
	}
}


/// @brief Return PWM value
/// @return Value [-100..+100]
int32_t EscDriver::getPwm ()
{
	return motorPwm_;
}
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

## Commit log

2025-11-09 Initial version 0.1
    [PnP_RC_Engine_Sound_ESP32_B_back.csv, PnP_RC_Engine_Sound_ESP32_B_front.csv, RC_Engine_Sound_ESP32_B.brd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]
2026-01-27 Refactor RxChannel class and related files for improved functionality and clarity
    - Added binary value to RxChannel for CRSF/SBUS communication.
    - Introduced switchBits_ and switchLatchs_ for multiswitch handling.
    - Updated process method to include failsafe handling and improved integrator logic.
    - Implemented GetMix4 and GetMix3P methods for multiswitch state retrieval.
    - Adjusted CRSF protocol definitions for channel value mapping.
    - Removed unused rcTrigger and statusLED classes to streamline codebase.
    - Enhanced RxCrsf and RxSbus classes for better channel data handling.
    - Updated AlfredoCRSF to support raw channel access.
    [Outputs.cpp, boulogne.h, civelier.h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]
2026-03-02 Add TFT dashboard support; ESC ramp param
    Introduce TFT dashboard support and related assets (DIYGuy999 std and Frevic)

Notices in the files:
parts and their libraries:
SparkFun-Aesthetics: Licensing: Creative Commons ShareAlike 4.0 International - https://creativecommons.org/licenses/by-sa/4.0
